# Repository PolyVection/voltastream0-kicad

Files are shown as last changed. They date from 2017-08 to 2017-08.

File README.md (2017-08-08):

# VoltaStream ZERO hardware 

VoltaStream ZERO

PolyVection VoltaStream ZERO is an open source audio streaming solution that runs Linux and features a high quality digital-to-analog converter as well as digital TOSLINK output capability. There is also a 40 way pinheader with access to 28 GPIO's. It is as small as 65 mm x 30 mm and very efficient. This PCB was created using KiCAD 4.0.5.
The whole project is released under the Creative Commons BY-NC-ND 3.0 license. 
For details please refere to the full license text at https://creativecommons.org/licenses/by-nc-nd/3.0/legalcode

If you have any questions don't hesitate to contact us. We are also offering customisation and prototyping services. http://www.voltastream.com

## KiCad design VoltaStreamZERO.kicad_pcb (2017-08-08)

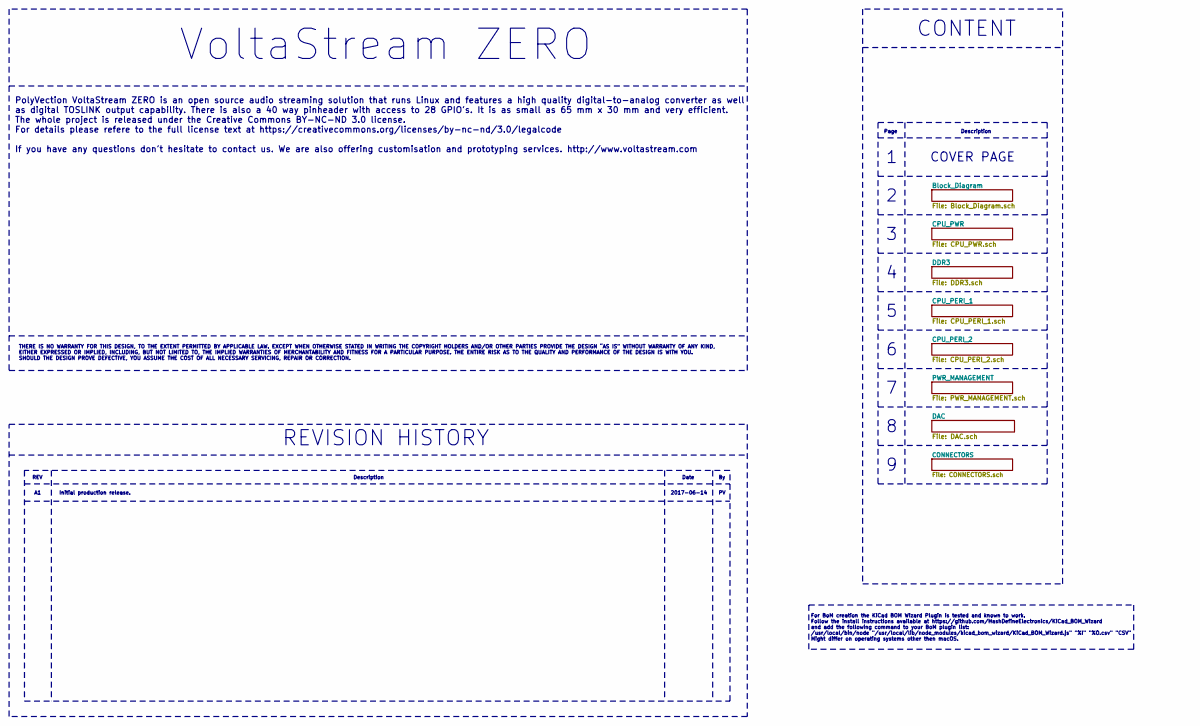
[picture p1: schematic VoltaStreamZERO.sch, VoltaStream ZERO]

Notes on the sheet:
VoltaStream ZERO
REVISION HISTORY
CONTENT
THERE IS NO WARRANTY FOR THIS DESIGN, TO THE EXTENT PERMITTED BY APPLICABLE LAW. EXCEPT WHEN OTHERWISE STATED IN WRITING THE COPYRIGHT HOLDERS AND/OR OTHER PARTIES PROVIDE THE DESIGN “AS IS” WITHOUT WARRANTY OF ANY KIND, EITHER EXPRESSED OR IMPLIED, INCLUDING, BUT NOT LIMITED TO, THE IMPLIED WARRAN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
PolyVection VoltaStream ZERO is an open source audio streaming solution that runs Linux and features a high quality digital-to-analog converter as well as digital TOSLINK output capability. There is also a 40 way pinheader with access to 28 GPIO's. It is as small as 65 mm x 30 mm and very efficient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
Page
Description
COVER PAGE
For BoM creation the KiCad BOM Wizard Plugin is tested and known to work. Follow the install instructions available at https://github.com/HashDefineElectronics/KiCad_BOM_Wizard and add the following command to your BoM plugin list: /usr/local/bin/node "/usr/local/lib/node_modules/kicad_bom_wizard/K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
REV
Date
Initial production release.
2017-06-14

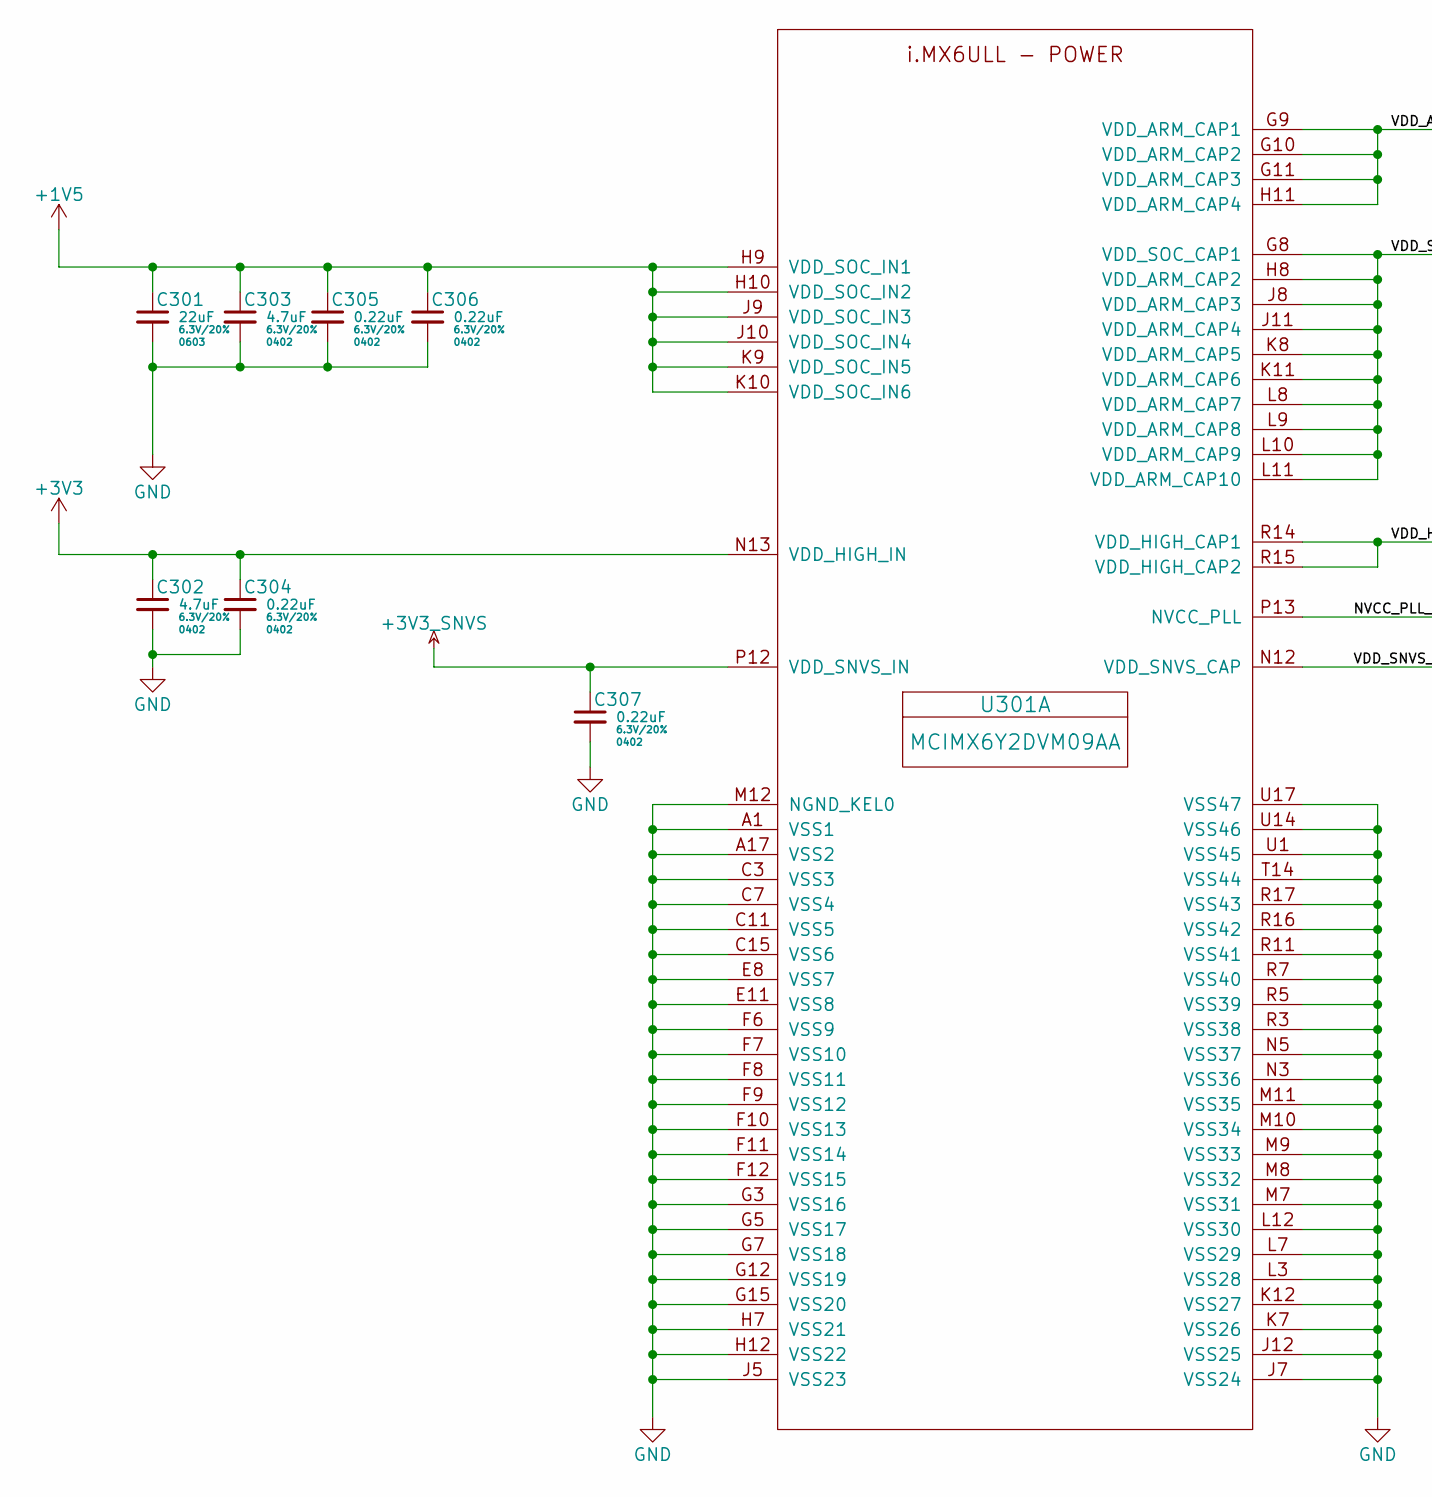
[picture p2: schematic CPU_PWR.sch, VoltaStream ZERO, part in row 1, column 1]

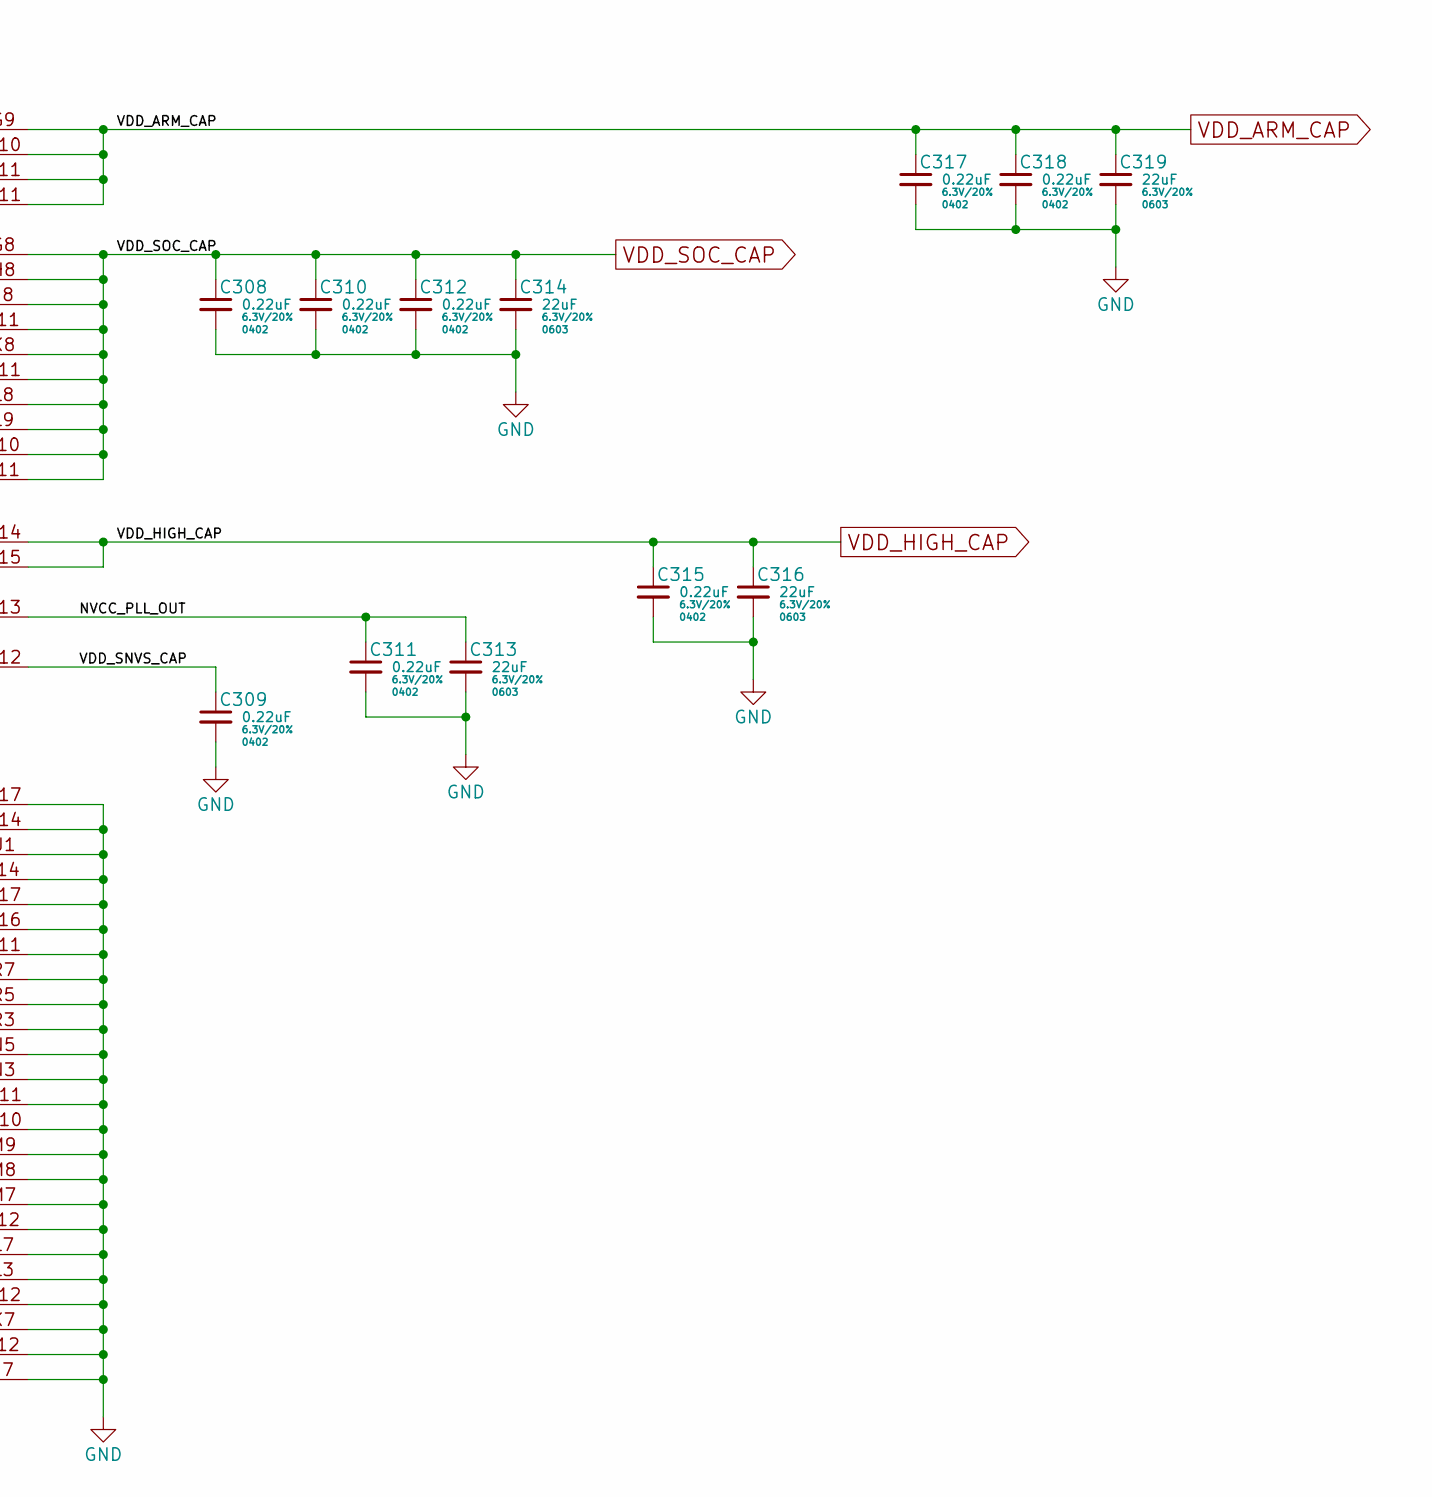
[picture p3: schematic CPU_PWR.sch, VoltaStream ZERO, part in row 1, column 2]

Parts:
C301, C313, C314, C316, C319: 22uF; 0603; Rating 6.3V/20%; Rating2 X5R; Part GRM188R60J226ME0D
C302, C303: 4.7uF; 0402; Rating 6.3V/20%; Rating2 X5R; Part GRM155R60J475ME7D
C304, C305, C306, C307, C308, C309, C310, C311, C312, C315, C317, C318: 0.22uF; 0402; Rating 6.3V/20%; Rating2 X5R; Part GRM155R60J224KE01D
U301: MCIMX6Y2DVM09AA; BGA_14x14; Rating 1x 900 MHz, 32 bit; Part MCIMX6Y2DVM09AA

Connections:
+1V5: C301.1, C303.1, C305.1, C306.1, U301.H9 (VDD_SOC_IN1), U301.H10 (VDD_SOC_IN2), U301.J9 (VDD_SOC_IN3), U301.J10 (VDD_SOC_IN4), U301.K9 (VDD_SOC_IN5), U301.K10 (VDD_SOC_IN6); also elsewhere on the board
+3V3: C302.1, C304.1, U301.N13 (VDD_HIGH_IN); also elsewhere on the board
+3V3_SNVS: C307.1, U301.P12 (VDD_SNVS_IN); also elsewhere on the board
/CPU_PWR/NVCC_PLL_OUT: C311.1, C313.1, U301.P13 (NVCC_PLL)
/CPU_PWR/VDD_SNVS_CAP: C309.1, U301.N12 (VDD_SNVS_CAP)
GND: C301.2, C302.2, C303.2, C304.2, C305.2, C306.2, C307.2, C308.2, C309.2, C310.2, C311.2, C312.2, C313.2, C314.2, C315.2, C316.2, C317.2, C318.2, C319.2, U301.A1 (VSS1), U301.A17 (VSS2), U301.C3 (VSS3), U301.C7 (VSS4), U301.C11 (VSS5), U301.C15 (VSS6), U301.E8 (VSS7), U301.E11 (VSS8), U301.F6 (VSS9), U301.F7 (VSS10), U301.F8 (VSS11), U301.F9 (VSS12), U301.F10 (VSS13), U301.F11 (VSS14), U301.F12 (VSS15), U301.G3 (VSS16), U301.G5 (VSS17), U301.G7 (VSS18), U301.G12 (VSS19), U301.G15 (VSS20), U301.H7 (VSS21), U301.H12 (VSS22), U301.J5 (VSS23), U301.J7 (VSS24), U301.J12 (VSS25), U301.K7 (VSS26), U301.K12 (VSS27), U301.L3 (VSS28), U301.L7 (VSS29), U301.L12 (VSS30), U301.M7 (VSS31), U301.M8 (VSS32), U301.M9 (VSS33), U301.M10 (VSS34), U301.M11 (VSS35), U301.M12 (NGND_KEL0), U301.N3 (VSS36), U301.N5 (VSS37), U301.R3 (VSS38), U301.R5 (VSS39), U301.R7 (VSS40), U301.R11 (VSS41), U301.R16 (VSS42), U301.R17 (VSS43), U301.T14 (VSS44), U301.U1 (VSS45), U301.U14 (VSS46), U301.U17 (VSS47); also elsewhere on the board
VDD_ARM_CAP: C317.1, C318.1, C319.1, U301.G9 (VDD_ARM_CAP1), U301.G10 (VDD_ARM_CAP2), U301.G11 (VDD_ARM_CAP3), U301.H11 (VDD_ARM_CAP4)
VDD_HIGH_CAP: C315.1, C316.1, U301.R14 (VDD_HIGH_CAP1), U301.R15 (VDD_HIGH_CAP2); also elsewhere on the board
VDD_SOC_CAP: C308.1, C310.1, C312.1, C314.1, U301.G8 (VDD_SOC_CAP1), U301.H8 (VDD_ARM_CAP2), U301.J8 (VDD_ARM_CAP3), U301.J11 (VDD_ARM_CAP4), U301.K8 (VDD_ARM_CAP5), U301.K11 (VDD_ARM_CAP6), U301.L8 (VDD_ARM_CAP7), U301.L9 (VDD_ARM_CAP8), U301.L10 (VDD_ARM_CAP9), U301.L11 (VDD_ARM_CAP10)

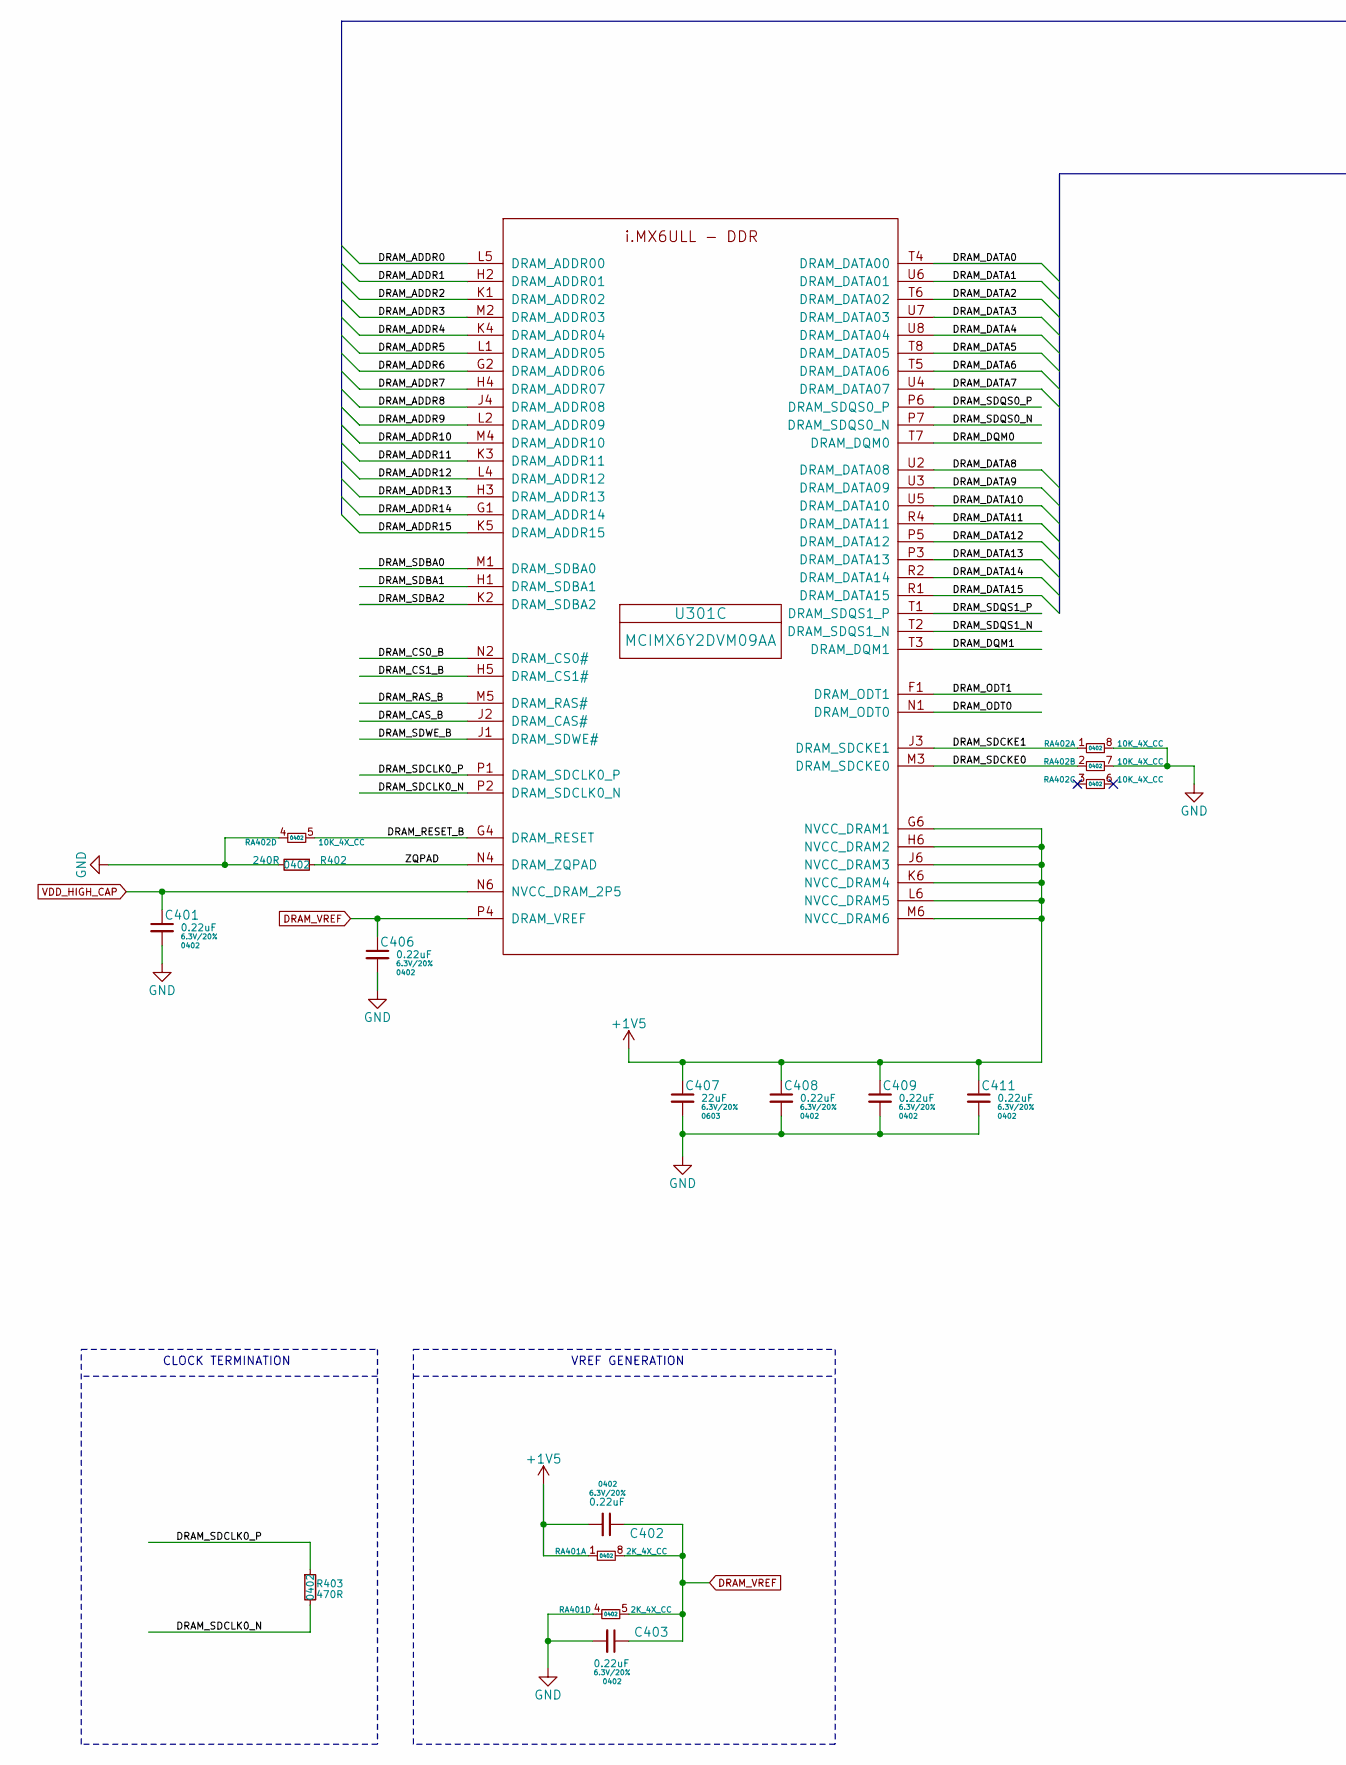
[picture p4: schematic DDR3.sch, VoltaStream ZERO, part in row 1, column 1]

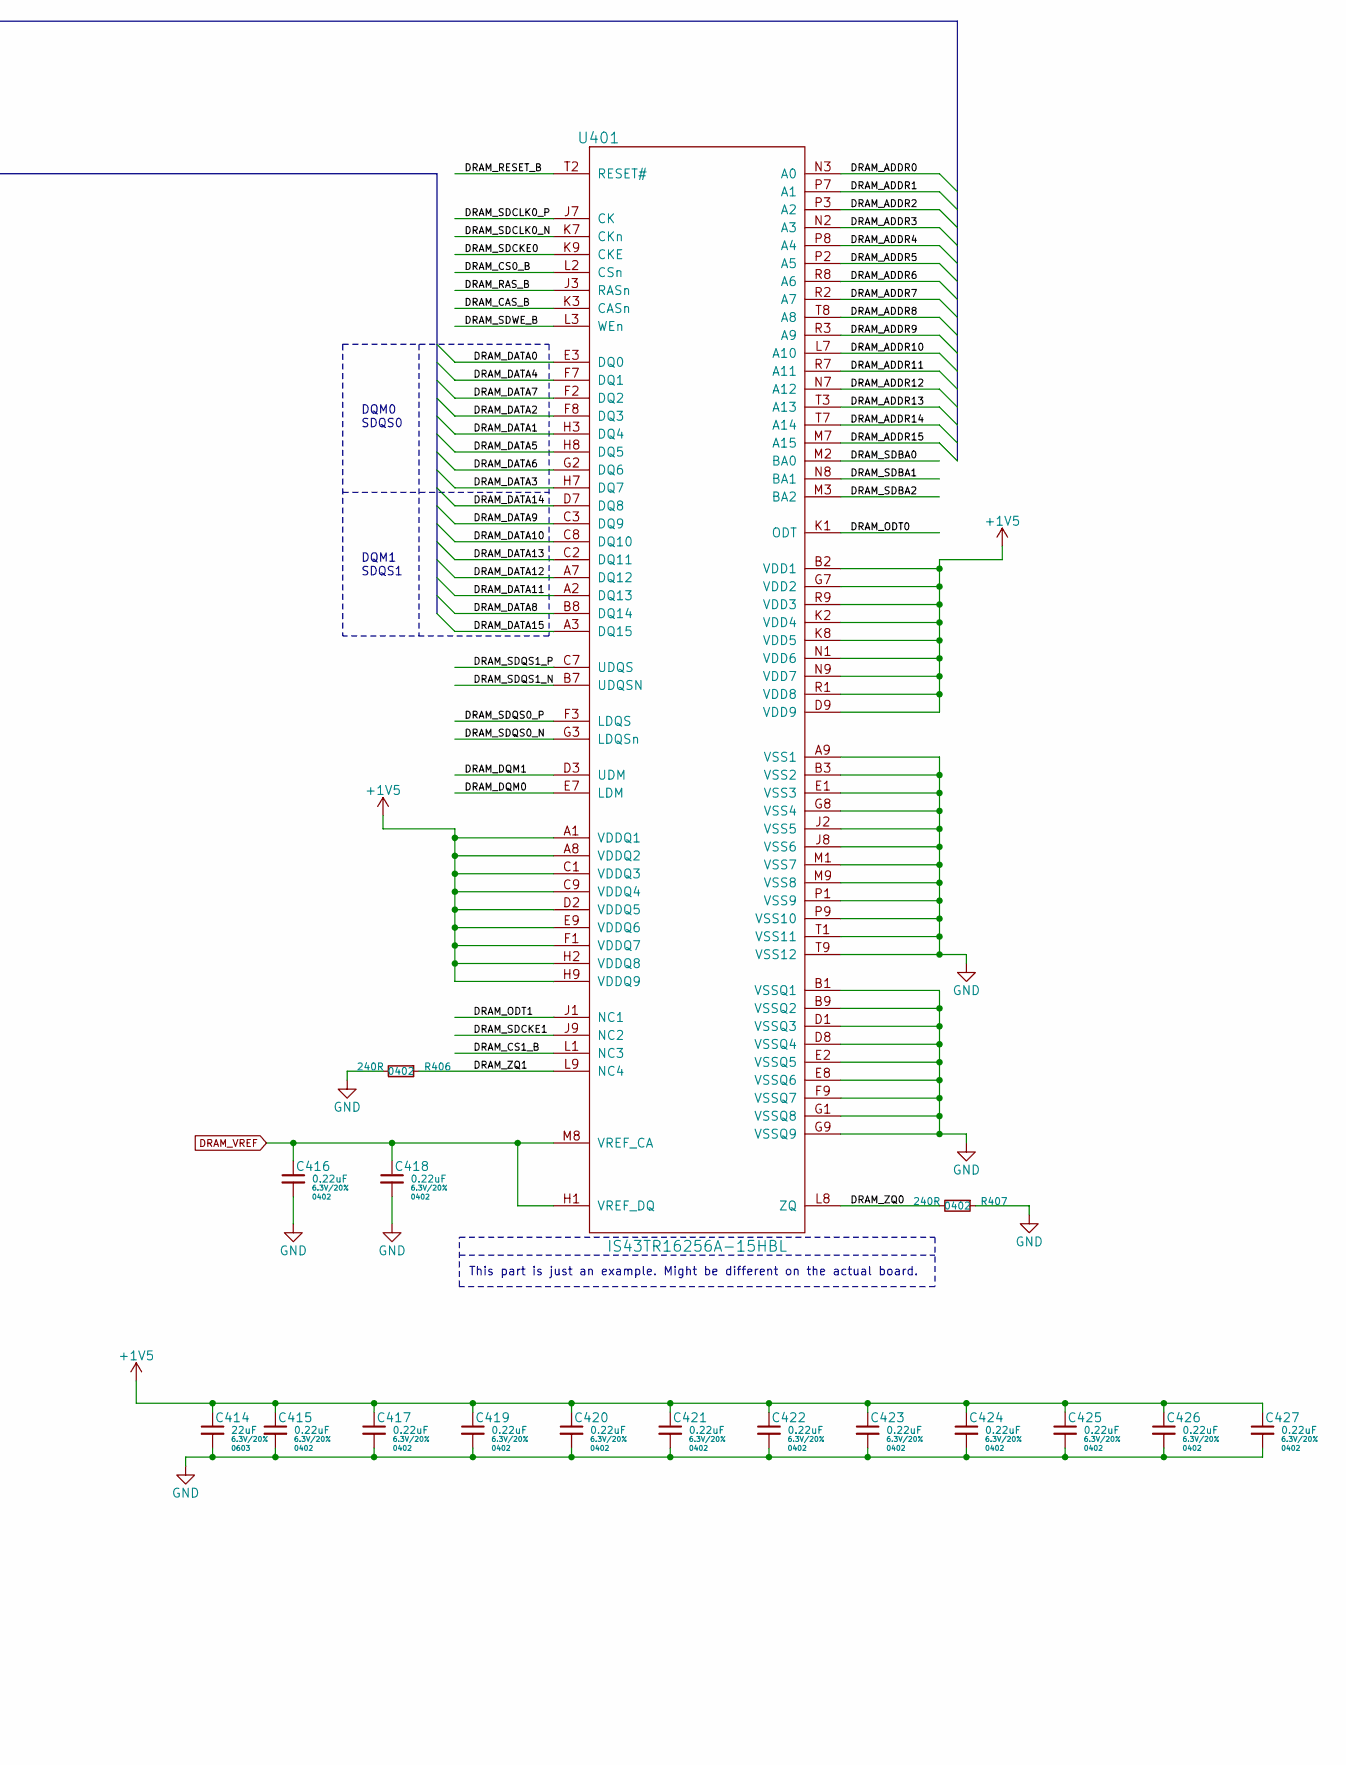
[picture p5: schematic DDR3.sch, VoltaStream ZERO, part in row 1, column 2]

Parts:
C401, C402, C403, C406, C408, C409, C411, C415, C416, C417, C418, C419, C420, C421, C422, C423, C424, C425, C426, C427: 0.22uF; 0402; Rating 6.3V/20%; Rating2 X5R; Part GRM155R60J224KE01D
C407, C414: 22uF; 0603; Rating 6.3V/20%; Rating2 X5R; Part GRM188R60J226ME0D
R402, R406, R407: 240R; 0402; Rating 1% / Thick Film; Part RC0402FR-07240RL
R403: 470R; 0402; Rating 1% / Thick Film; Part RC0402FR-07470RL
RA401: 2K_4X_CC; R_Array_OPT_4x0402; Rating 2K, 5%; Rating2 Concave Array 4x; Part EXB-N8V202JX
RA402: 10K_4X_CC; R_Array_OPT_4x0402; Rating 10K, 5%; Rating2 Concave Array 4x; Part EXB-N8V103JX
U301: MCIMX6Y2DVM09AA; BGA_14x14; Rating 1x 900 MHz, 32 bit; Part MCIMX6Y2DVM09AA
U401: IS43TR16256A-15HBL; FBGA_96_DDR3L; Rating 4G - DDR3; Rating2 512 MB - 1V5; Part IS43TR16256A-15HBL

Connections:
+1V5: C402.2, C407.1, C408.1, C409.1, C411.1, C414.1, C415.1, C417.1, C419.1, C420.1, C421.1, C422.1, C423.1, C424.1, C425.1, C426.1, C427.1, RA401.1, U301.G6 (NVCC_DRAM1), U301.H6 (NVCC_DRAM2), U301.J6 (NVCC_DRAM3), U301.K6 (NVCC_DRAM4), U301.L6 (NVCC_DRAM5), U301.M6 (NVCC_DRAM6), U401.A1 (VDDQ1), U401.A8 (VDDQ2), U401.B2 (VDD1), U401.C1 (VDDQ3), U401.C9 (VDDQ4), U401.D2 (VDDQ5), U401.D9 (VDD9), U401.E9 (VDDQ6), U401.F1 (VDDQ7), U401.G7 (VDD2), U401.H2 (VDDQ8), U401.H9 (VDDQ9), U401.K2 (VDD4), U401.K8 (VDD5), U401.N1 (VDD6), U401.N9 (VDD7), U401.R1 (VDD8), U401.R9 (VDD3); also elsewhere on the board
/DDR3/DRAM_ADDR0: U301.L5 (DRAM_ADDR00), U401.N3 (A0)
/DDR3/DRAM_ADDR1: U301.H2 (DRAM_ADDR01), U401.P7 (A1)
/DDR3/DRAM_ADDR2: U301.K1 (DRAM_ADDR02), U401.P3 (A2)
/DDR3/DRAM_ADDR3: U301.M2 (DRAM_ADDR03), U401.N2 (A3)
/DDR3/DRAM_ADDR4: U301.K4 (DRAM_ADDR04), U401.P8 (A4)
/DDR3/DRAM_ADDR5: U301.L1 (DRAM_ADDR05), U401.P2 (A5)
/DDR3/DRAM_ADDR6: U301.G2 (DRAM_ADDR06), U401.R8 (A6)
/DDR3/DRAM_ADDR7: U301.H4 (DRAM_ADDR07), U401.R2 (A7)
/DDR3/DRAM_ADDR8: U301.J4 (DRAM_ADDR08), U401.T8 (A8)
/DDR3/DRAM_ADDR9: U301.L2 (DRAM_ADDR09), U401.R3 (A9)
/DDR3/DRAM_ADDR10: U301.M4 (DRAM_ADDR10), U401.L7 (A10)
/DDR3/DRAM_ADDR11: U301.K3 (DRAM_ADDR11), U401.R7 (A11)
/DDR3/DRAM_ADDR12: U301.L4 (DRAM_ADDR12), U401.N7 (A12)
/DDR3/DRAM_ADDR13: U301.H3 (DRAM_ADDR13), U401.T3 (A13)
/DDR3/DRAM_ADDR14: U301.G1 (DRAM_ADDR14), U401.T7 (A14)
/DDR3/DRAM_ADDR15: U301.K5 (DRAM_ADDR15), U401.M7 (A15)
/DDR3/DRAM_CAS_B: U301.J2 (DRAM_CAS#), U401.K3 (CASn)
/DDR3/DRAM_CS0_B: U301.N2 (DRAM_CS0#), U401.L2 (CSn)
/DDR3/DRAM_CS1_B: U301.H5 (DRAM_CS1#), U401.L1 (NC3)
/DDR3/DRAM_DATA0: U301.T4 (DRAM_DATA00), U401.E3 (DQ0)
/DDR3/DRAM_DATA1: U301.U6 (DRAM_DATA01), U401.H3 (DQ4)
/DDR3/DRAM_DATA2: U301.T6 (DRAM_DATA02), U401.F8 (DQ3)
/DDR3/DRAM_DATA3: U301.U7 (DRAM_DATA03), U401.H7 (DQ7)
/DDR3/DRAM_DATA4: U301.U8 (DRAM_DATA04), U401.F7 (DQ1)
/DDR3/DRAM_DATA5: U301.T8 (DRAM_DATA05), U401.H8 (DQ5)
/DDR3/DRAM_DATA6: U301.T5 (DRAM_DATA06), U401.G2 (DQ6)
/DDR3/DRAM_DATA7: U301.U4 (DRAM_DATA07), U401.F2 (DQ2)
/DDR3/DRAM_DATA8: U301.U2 (DRAM_DATA08), U401.B8 (DQ14)
/DDR3/DRAM_DATA9: U301.U3 (DRAM_DATA09), U401.C3 (DQ9)
/DDR3/DRAM_DATA10: U301.U5 (DRAM_DATA10), U401.C8 (DQ10)
/DDR3/DRAM_DATA11: U301.R4 (DRAM_DATA11), U401.A2 (DQ13)
/DDR3/DRAM_DATA12: U301.P5 (DRAM_DATA12), U401.A7 (DQ12)
/DDR3/DRAM_DATA13: U301.P3 (DRAM_DATA13), U401.C2 (DQ11)
/DDR3/DRAM_DATA14: U301.R2 (DRAM_DATA14), U401.D7 (DQ8)
/DDR3/DRAM_DATA15: U301.R1 (DRAM_DATA15), U401.A3 (DQ15)
/DDR3/DRAM_DQM0: U301.T7 (DRAM_DQM0), U401.E7 (LDM)
/DDR3/DRAM_DQM1: U301.T3 (DRAM_DQM1), U401.D3 (UDM)
/DDR3/DRAM_ODT0: U301.N1 (DRAM_ODT0), U401.K1 (ODT)
/DDR3/DRAM_ODT1: U301.F1 (DRAM_ODT1), U401.J1 (NC1)
/DDR3/DRAM_RAS_B: U301.M5 (DRAM_RAS#), U401.J3 (RASn)
/DDR3/DRAM_RESET_B: RA402.5 (R1), U301.G4 (DRAM_RESET), U401.T2 (RESET#)
/DDR3/DRAM_SDBA0: U301.M1 (DRAM_SDBA0), U401.M2 (BA0)
/DDR3/DRAM_SDBA1: U301.H1 (DRAM_SDBA1), U401.N8 (BA1)
/DDR3/DRAM_SDBA2: U301.K2 (DRAM_SDBA2), U401.M3 (BA2)
/DDR3/DRAM_SDCKE0: RA402.2 (P1), U301.M3 (DRAM_SDCKE0), U401.K9 (CKE)
/DDR3/DRAM_SDCKE1: RA402.1, U301.J3 (DRAM_SDCKE1), U401.J9 (NC2)
/DDR3/DRAM_SDCLK0_N: R403.2, U301.P2 (DRAM_SDCLK0_N), U401.K7 (CKn)
/DDR3/DRAM_SDCLK0_P: R403.1, U301.P1 (DRAM_SDCLK0_P), U401.J7 (CK)
/DDR3/DRAM_SDQS0_N: U301.P7 (DRAM_SDQS0_N), U401.G3 (LDQSn)
/DDR3/DRAM_SDQS0_P: U301.P6 (DRAM_SDQS0_P), U401.F3 (LDQS)
/DDR3/DRAM_SDQS1_N: U301.T2 (DRAM_SDQS1_N), U401.B7 (UDQSN)
/DDR3/DRAM_SDQS1_P: U301.T1 (DRAM_SDQS1_P), U401.C7 (UDQS)
/DDR3/DRAM_SDWE_B: U301.J1 (DRAM_SDWE#), U401.L3 (WEn)
/DDR3/DRAM_ZQ0: R407.2, U401.L8 (ZQ)
/DDR3/DRAM_ZQ1: R406.1, U401.L9 (NC4)
/DDR3/ZQPAD: R402.1, U301.N4 (DRAM_ZQPAD)
DRAM_VREF: C402.1, C403.1, C406.1, C416.1, C418.1, RA401.5 (R1), RA401.8 (R1), U301.P4 (DRAM_VREF), U401.H1 (VREF_DQ), U401.M8 (VREF_CA)
GND: C401.2, C403.2, C406.2, C407.2, C408.2, C409.2, C411.2, C414.2, C415.2, C416.2, C417.2, C418.2, C419.2, C420.2, C421.2, C422.2, C423.2, C424.2, C425.2, C426.2, C427.2, R402.2, R406.2, R407.1, RA401.4 (P1), RA402.4 (P1), RA402.7 (R1), RA402.8 (R1), U401.A9 (VSS1), U401.B1 (VSSQ1), U401.B3 (VSS2), U401.B9 (VSSQ2), U401.D1 (VSSQ3), U401.D8 (VSSQ4), U401.E1 (VSS3), U401.E2 (VSSQ5), U401.E8 (VSSQ6), U401.F9 (VSSQ7), U401.G1 (VSSQ8), U401.G8 (VSS4), U401.G9 (VSSQ9), U401.J2 (VSS5), U401.J8 (VSS6), U401.M1 (VSS7), U401.M9 (VSS8), U401.P1 (VSS9), U401.P9 (VSS10), U401.T1 (VSS11), U401.T9 (VSS12); also elsewhere on the board
VDD_HIGH_CAP: C401.1, U301.N6 (NVCC_DRAM_2P5); also elsewhere on the board

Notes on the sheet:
CLOCK TERMINATION
VREF GENERATION
This part is just an example. Might be different on the actual board.
DQM0 SDQS0
DQM1 SDQS1

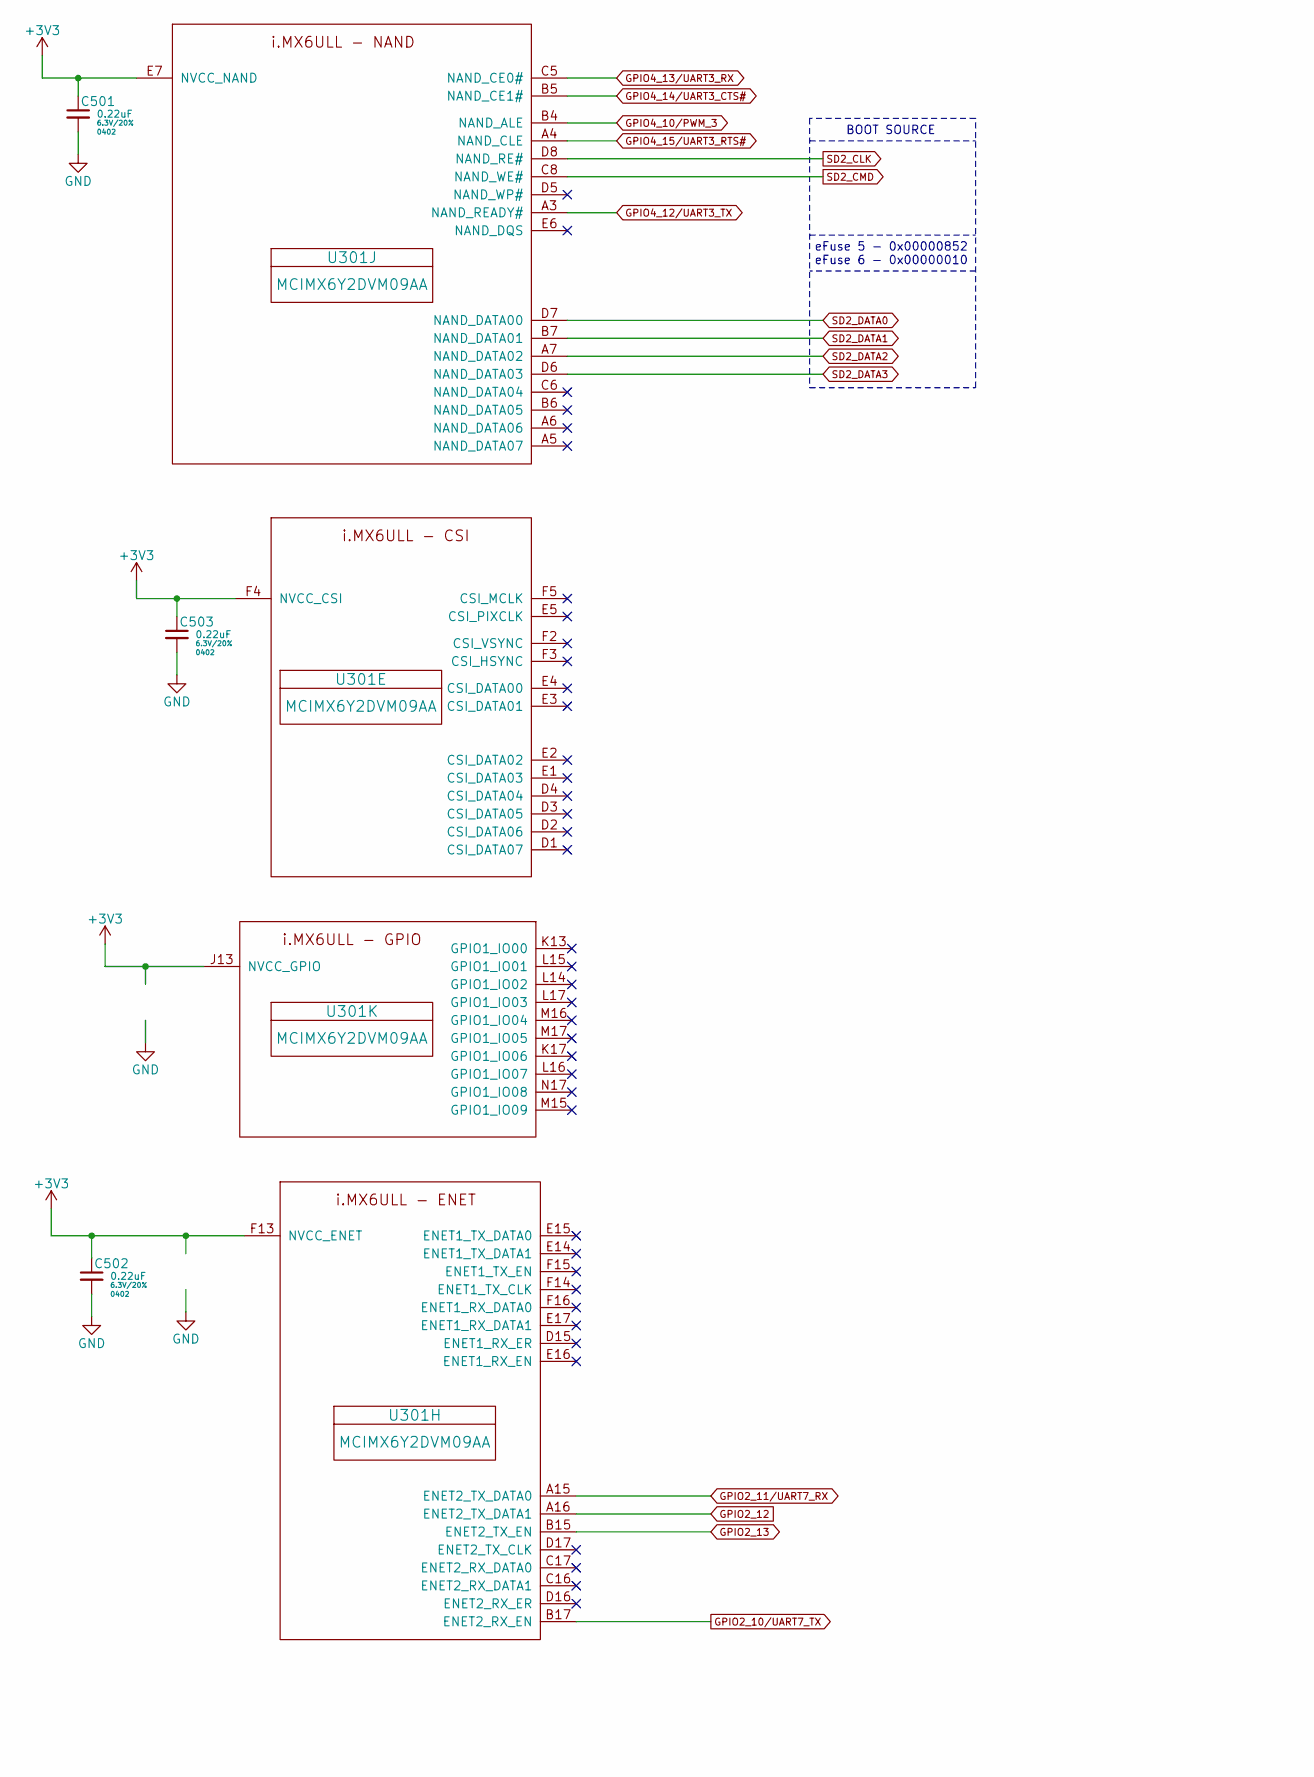
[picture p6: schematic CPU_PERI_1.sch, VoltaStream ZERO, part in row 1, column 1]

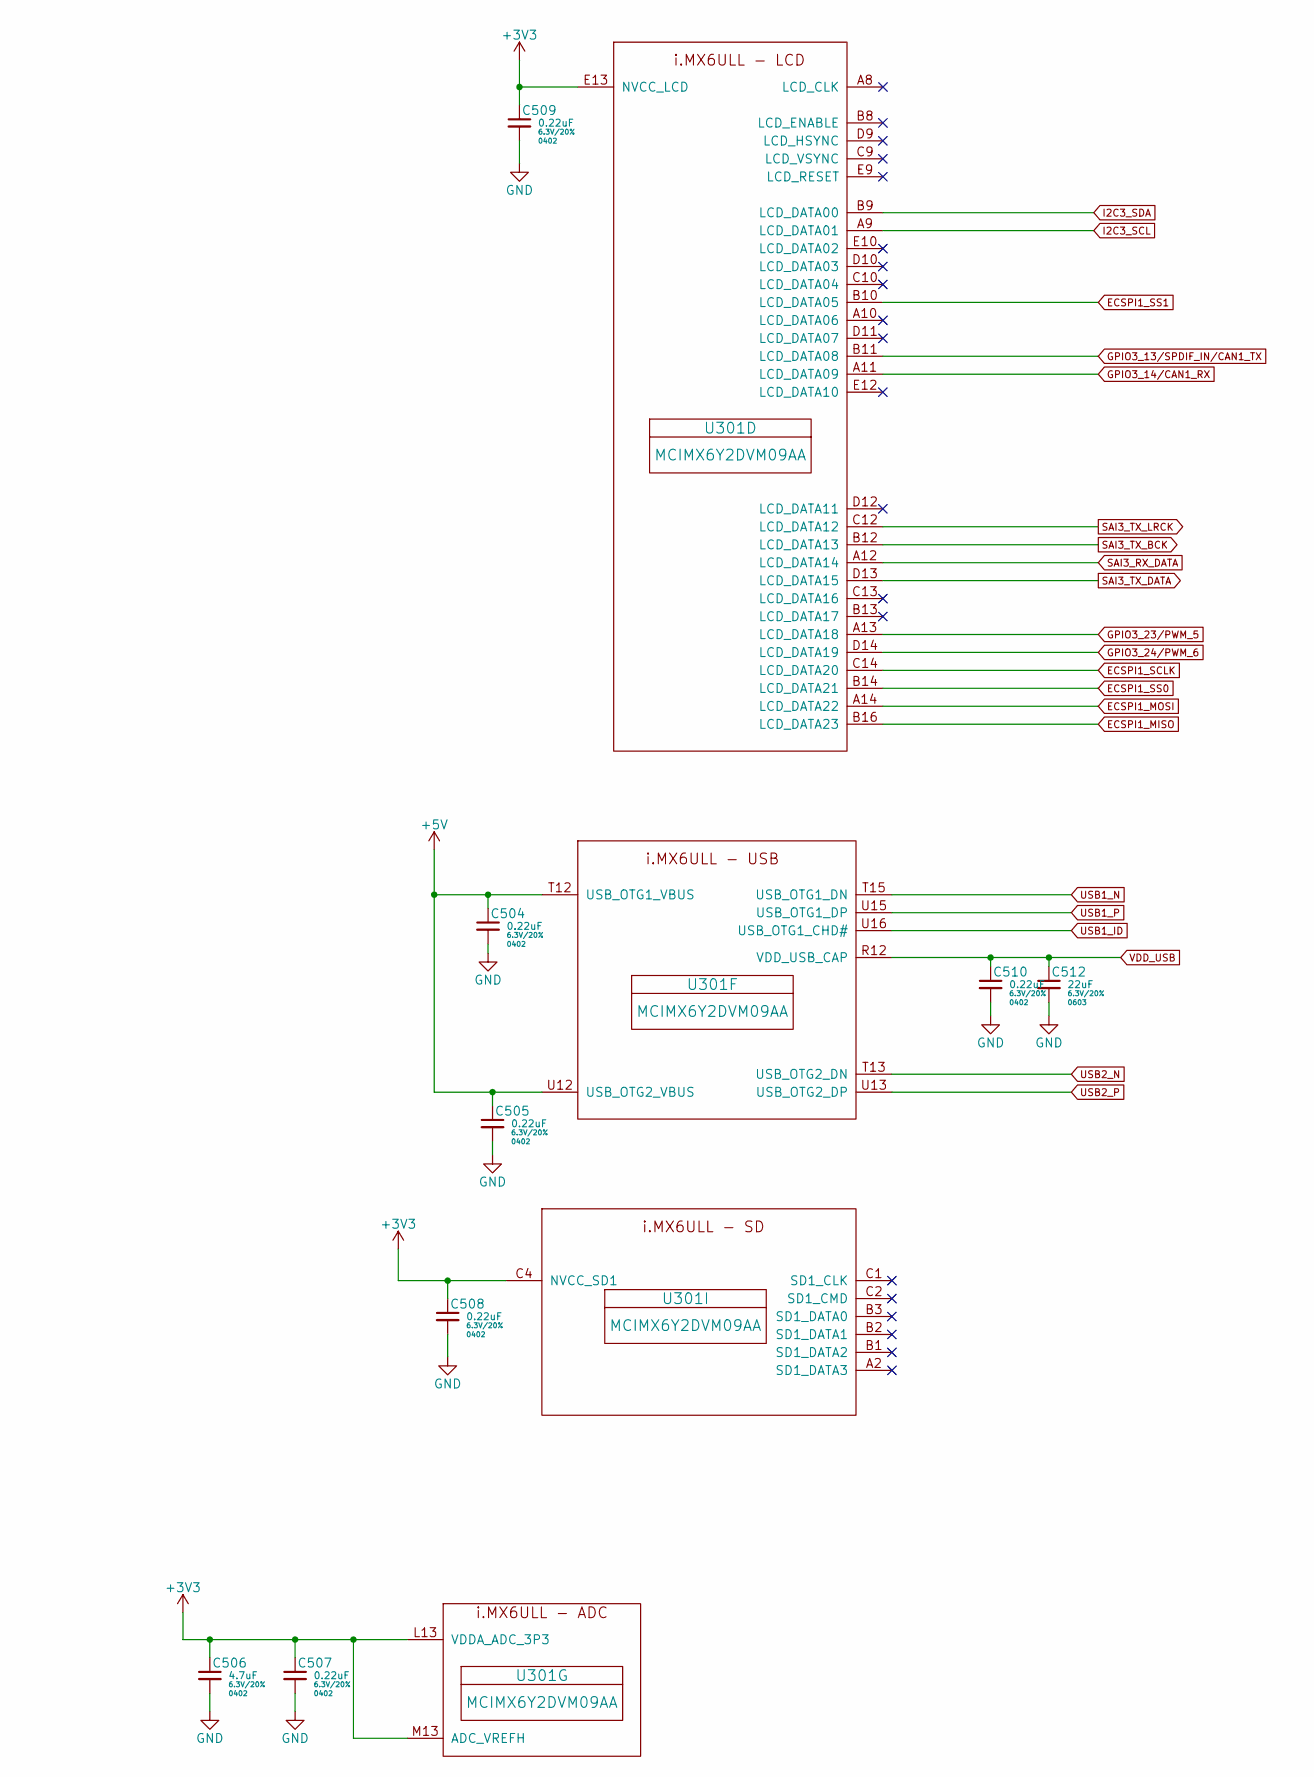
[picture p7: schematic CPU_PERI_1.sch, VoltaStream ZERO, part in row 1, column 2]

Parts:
C501, C502, C503, C504, C505, C507, C508, C509, C510: 0.22uF; 0402; Rating 6.3V/20%; Rating2 X5R; Part GRM155R60J224KE01D
C506: 4.7uF; 0402; Rating 6.3V/20%; Rating2 X5R; Part GRM155R60J475ME7D
C512: 22uF; 0603; Rating 6.3V/20%; Rating2 X5R; Part GRM188R60J226ME0D
U301: MCIMX6Y2DVM09AA; BGA_14x14; Rating 1x 900 MHz, 32 bit; Part MCIMX6Y2DVM09AA

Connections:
+3V3: C501.1, C502.1, C503.1, C506.1, C507.1, C508.1, C509.1, U301.C4 (NVCC_SD1), U301.E7 (NVCC_NAND), U301.E13 (NVCC_LCD), U301.F4 (NVCC_CSI), U301.F13 (NVCC_ENET), U301.J13 (NVCC_GPIO), U301.L13 (VDDA_ADC_3P3), U301.M13 (ADC_VREFH); also elsewhere on the board
+5V: C504.1, C505.1, U301.T12 (USB_OTG1_VBUS), U301.U12 (USB_OTG2_VBUS); also elsewhere on the board
ECSPI1_MISO: U301.B16 (LCD_DATA23); also elsewhere on the board
ECSPI1_MOSI: U301.A14 (LCD_DATA22); also elsewhere on the board
ECSPI1_SCLK: U301.C14 (LCD_DATA20); also elsewhere on the board
ECSPI1_SS0: U301.B14 (LCD_DATA21); also elsewhere on the board
ECSPI1_SS1: U301.B10 (LCD_DATA05); also elsewhere on the board
GND: C501.2, C502.2, C503.2, C504.2, C505.2, C506.2, C507.2, C508.2, C509.2, C510.2, C512.2; also elsewhere on the board
GPIO2_10/UART7_TX: U301.B17 (ENET2_RX_EN); also elsewhere on the board
GPIO2_11/UART7_RX: U301.A15 (ENET2_TX_DATA0); also elsewhere on the board
GPIO2_12: U301.A16 (ENET2_TX_DATA1); also elsewhere on the board
GPIO2_13: U301.B15 (ENET2_TX_EN); also elsewhere on the board
GPIO3_13/SPDIF_IN/CAN1_TX: U301.B11 (LCD_DATA08); also elsewhere on the board
GPIO3_14/CAN1_RX: U301.A11 (LCD_DATA09); also elsewhere on the board
GPIO3_23/PWM_5: U301.A13 (LCD_DATA18); also elsewhere on the board
GPIO3_24/PWM_6: U301.D14 (LCD_DATA19); also elsewhere on the board
GPIO4_10/PWM_3: U301.B4 (NAND_ALE); also elsewhere on the board
GPIO4_12/UART3_TX: U301.A3 (NAND_READY#); also elsewhere on the board
GPIO4_13/UART3_RX: U301.C5 (NAND_CE0#); also elsewhere on the board
GPIO4_14/UART3_CTS#: U301.B5 (NAND_CE1#); also elsewhere on the board
GPIO4_15/UART3_RTS#: U301.A4 (NAND_CLE); also elsewhere on the board
I2C3_SCL: U301.A9 (LCD_DATA01); also elsewhere on the board
I2C3_SDA: U301.B9 (LCD_DATA00); also elsewhere on the board
SAI3_RX_DATA: U301.A12 (LCD_DATA14); also elsewhere on the board
SAI3_TX_BCK: U301.B12 (LCD_DATA13); also elsewhere on the board
SAI3_TX_DATA: U301.D13 (LCD_DATA15); also elsewhere on the board
SAI3_TX_LRCK: U301.C12 (LCD_DATA12); also elsewhere on the board
SD2_CLK: U301.D8 (NAND_RE#); also elsewhere on the board
SD2_CMD: U301.C8 (NAND_WE#); also elsewhere on the board
SD2_DATA0: U301.D7 (NAND_DATA00); also elsewhere on the board
SD2_DATA1: U301.B7 (NAND_DATA01); also elsewhere on the board
SD2_DATA2: U301.A7 (NAND_DATA02); also elsewhere on the board
SD2_DATA3: U301.D6 (NAND_DATA03); also elsewhere on the board
USB1_ID: U301.U16 (USB_OTG1_CHD#)
USB1_N: U301.T15 (USB_OTG1_DN); also elsewhere on the board
USB1_P: U301.U15 (USB_OTG1_DP); also elsewhere on the board
USB2_N: U301.T13 (USB_OTG2_DN); also elsewhere on the board
USB2_P: U301.U13 (USB_OTG2_DP); also elsewhere on the board
VDD_USB: C510.1, C512.1, U301.R12 (VDD_USB_CAP)

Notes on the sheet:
BOOT SOURCE
eFuse 5 - 0x00000852 eFuse 6 - 0x00000010

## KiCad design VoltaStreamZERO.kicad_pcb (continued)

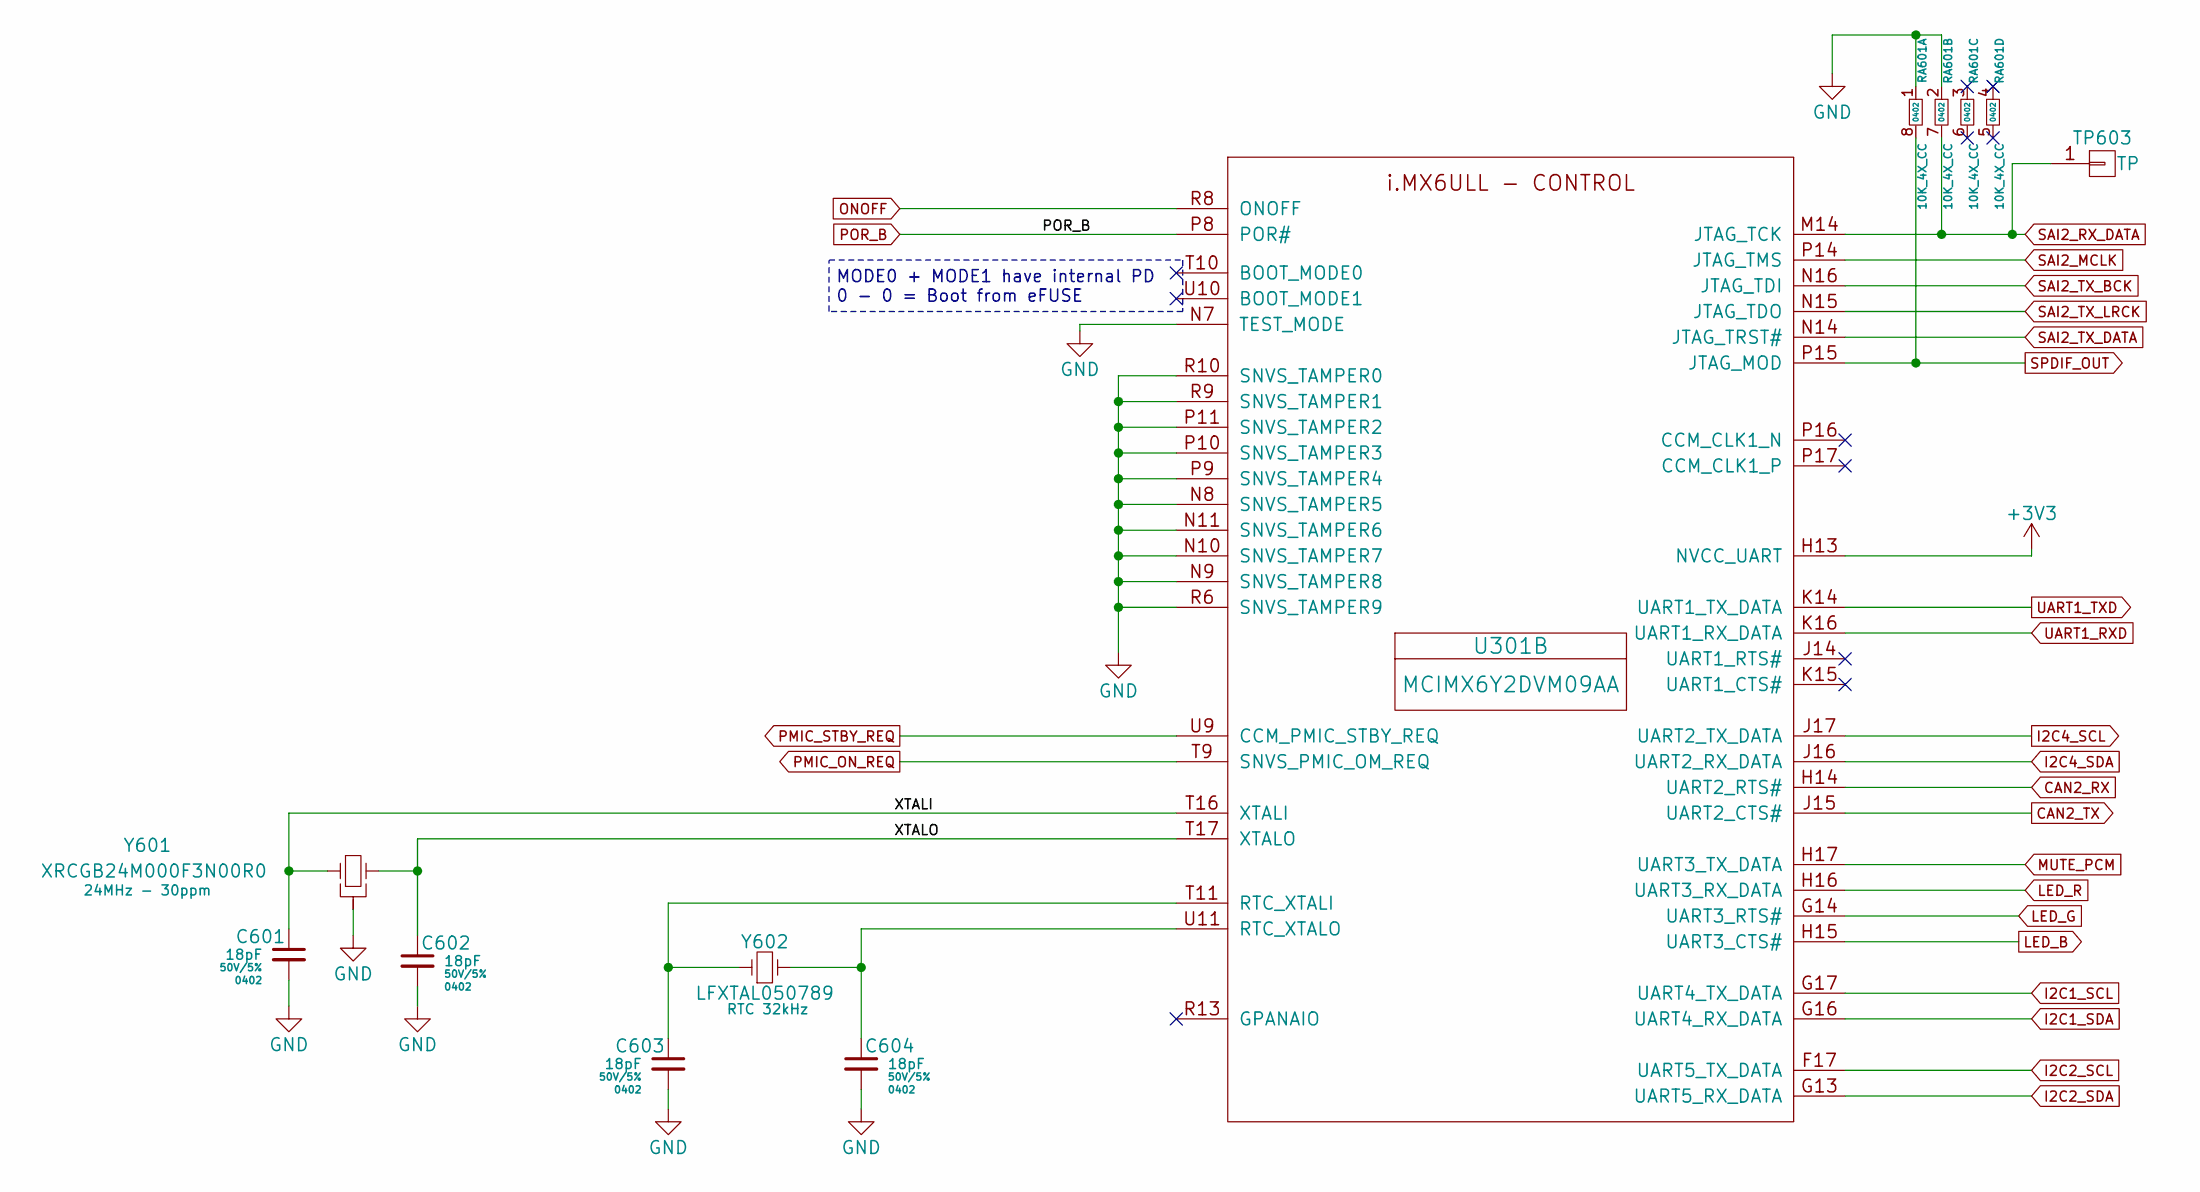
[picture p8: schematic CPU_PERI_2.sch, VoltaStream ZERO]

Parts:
C601, C602, C603, C604: 18pF; 0402; Rating 50V/5%; Rating2 C0G; Part GRM1555C1H180JA01D
RA601: 10K_4X_CC; R_Array_OPT_4x0402; Rating 10K, 5%; Rating2 Concave Array 4x; Part EXB-N8V103JX
TP603: TP; TP_10; Rating NoMask; Part TestPoint
U301: MCIMX6Y2DVM09AA; BGA_14x14; Rating 1x 900 MHz, 32 bit; Part MCIMX6Y2DVM09AA
Y601: XRCGB24M000F3N00R0; OSZ_2x1.6; Rating 24MHz - 30ppm; Rating2 6pF - 2x1.6mm; Part XRCGB24M000F3N00R0
Y602: LFXTAL050789; OSZ_2x1.2; Rating RTC 32kHz; Part LFXTAL050789Reel

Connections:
+3V3: U301.H13 (NVCC_UART); also elsewhere on the board
/CPU_PERI_2/XTALI: C601.1, U301.T16 (XTALI), Y601.1
/CPU_PERI_2/XTALO: C602.1, U301.T17 (XTALO), Y601.2
CAN2_RX: U301.H14 (UART2_RTS#)
CAN2_TX: U301.J15 (UART2_CTS#)
GND: C601.2, C602.2, C603.2, C604.2, RA601.1, RA601.2 (P1), U301.N7 (TEST_MODE), U301.N8 (SNVS_TAMPER5), U301.N9 (SNVS_TAMPER8), U301.N10 (SNVS_TAMPER7), U301.N11 (SNVS_TAMPER6), U301.P9 (SNVS_TAMPER4), U301.P10 (SNVS_TAMPER3), U301.P11 (SNVS_TAMPER2), U301.R6 (SNVS_TAMPER9), U301.R9 (SNVS_TAMPER1), U301.R10 (SNVS_TAMPER0), Y601.G; also elsewhere on the board
I2C1_SCL: U301.G17 (UART4_TX_DATA); also elsewhere on the board
I2C1_SDA: U301.G16 (UART4_RX_DATA); also elsewhere on the board
I2C2_SCL: U301.F17 (UART5_TX_DATA)
I2C2_SDA: U301.G13 (UART5_RX_DATA)
I2C4_SCL: U301.J17 (UART2_TX_DATA); also elsewhere on the board
I2C4_SDA: U301.J16 (UART2_RX_DATA); also elsewhere on the board
LED_B: U301.H15 (UART3_CTS#); also elsewhere on the board
LED_G: U301.G14 (UART3_RTS#); also elsewhere on the board
LED_R: U301.H16 (UART3_RX_DATA); also elsewhere on the board
MUTE_PCM: U301.H17 (UART3_TX_DATA); also elsewhere on the board
unnamed: C603.1, U301.T11 (RTC_XTALI), Y602.1
unnamed: C604.1, U301.U11 (RTC_XTALO), Y602.2
ONOFF: U301.R8 (ONOFF); also elsewhere on the board
PMIC_ON_REQ: U301.T9 (SNVS_PMIC_OM_REQ); also elsewhere on the board
PMIC_STBY_REQ: U301.U9 (CCM_PMIC_STBY_REQ)
POR_B: U301.P8 (POR#); also elsewhere on the board
SAI2_MCLK: U301.P14 (JTAG_TMS); also elsewhere on the board
SAI2_RX_DATA: RA601.7 (R1), TP603.1, U301.M14 (JTAG_TCK)
SAI2_TX_BCK: U301.N16 (JTAG_TDI); also elsewhere on the board
SAI2_TX_DATA: U301.N14 (JTAG_TRST#); also elsewhere on the board
SAI2_TX_LRCK: U301.N15 (JTAG_TDO); also elsewhere on the board
SPDIF_OUT: RA601.8 (R1), U301.P15 (JTAG_MOD); also elsewhere on the board
UART1_RXD: U301.K16 (UART1_RX_DATA); also elsewhere on the board
UART1_TXD: U301.K14 (UART1_TX_DATA); also elsewhere on the board

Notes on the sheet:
MODE0 + MODE1 have internal PD 0 - 0 = Boot from eFUSE

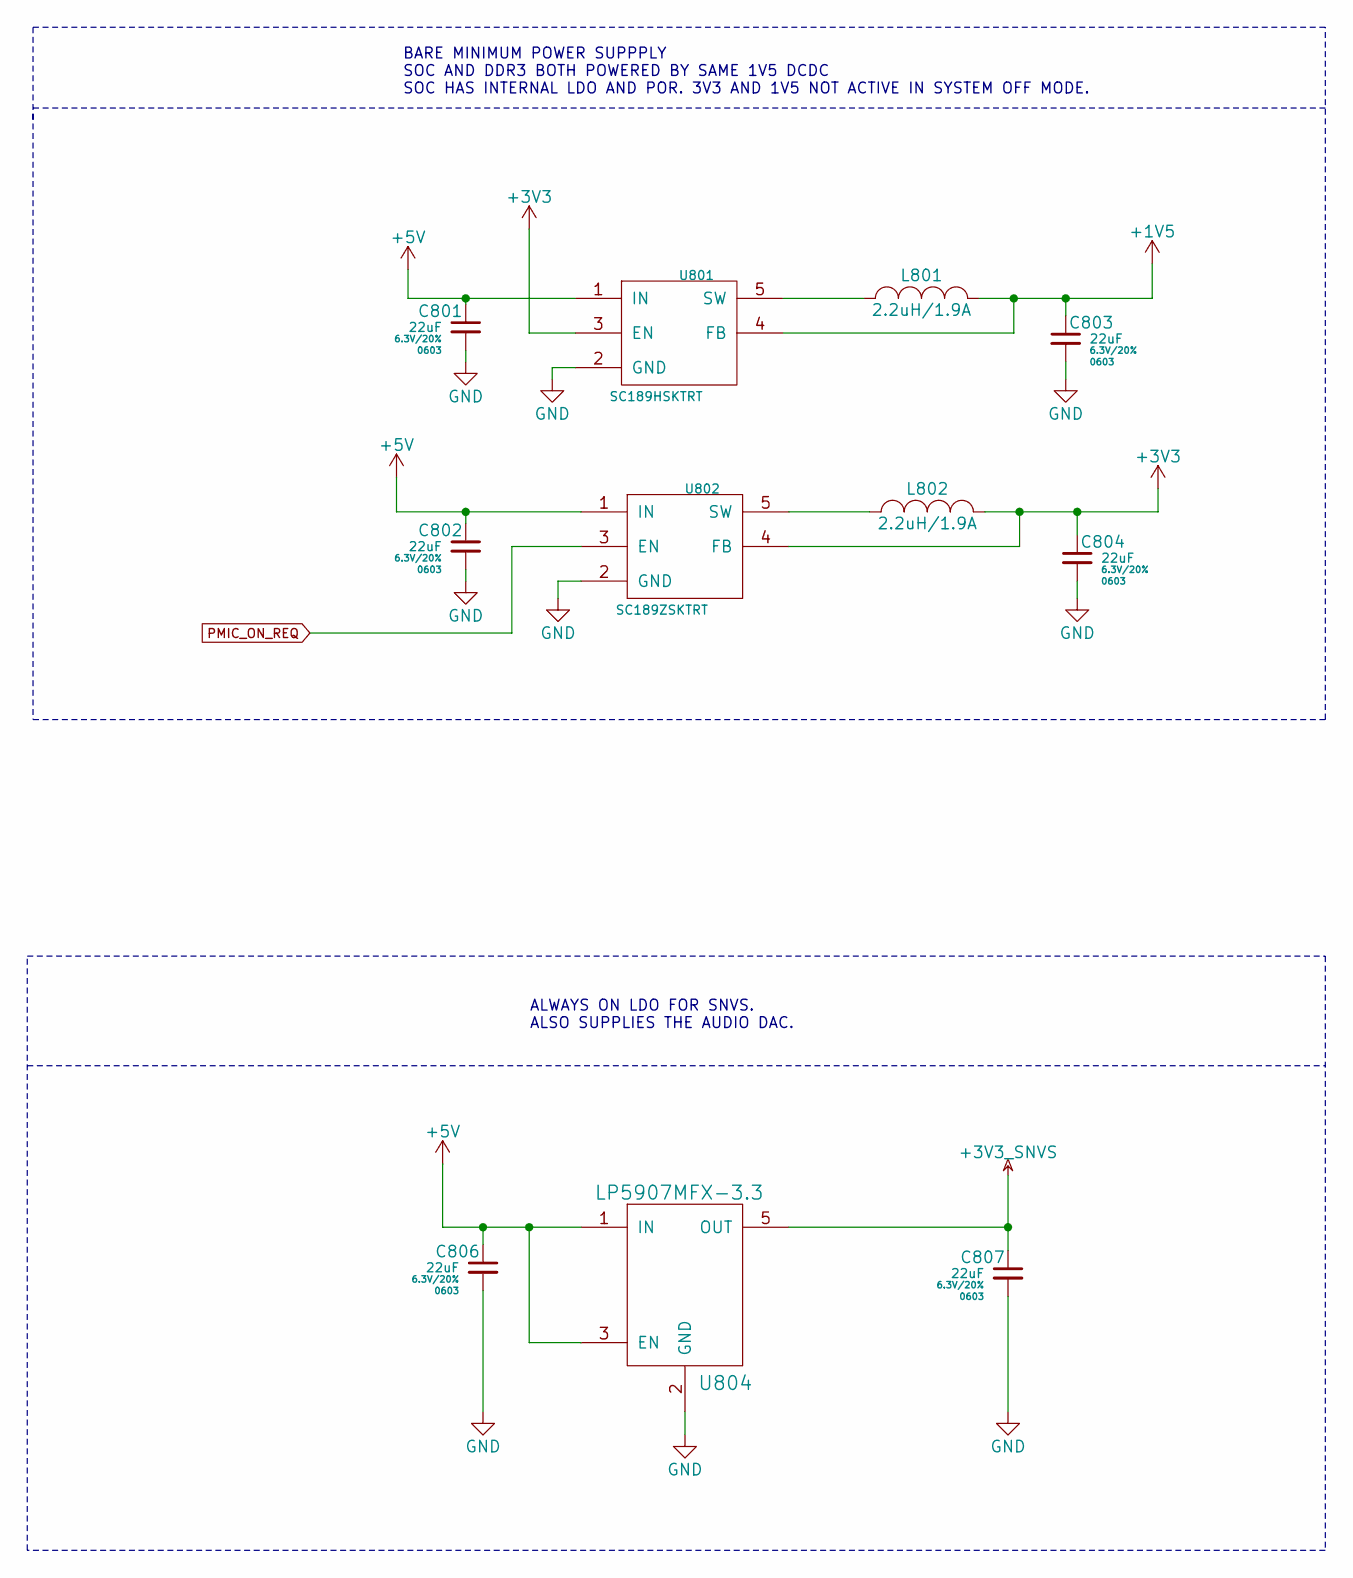
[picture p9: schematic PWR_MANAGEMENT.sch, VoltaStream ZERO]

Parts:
C801, C802, C803, C804, C806, C807: 22uF; 0603; Rating 6.3V/20%; Rating2 X5R; Part GRM188R60J226ME0D
L801, L802: 2.2uH/1.9A; MAMK2520T2R2M; Rating 2.2uH / 1.9A; Part MAMK2520T2R2M
U801: SC189HSKTRT; SOT-23-5; Rating 1V5 1.5A 2.5MHz; Rating2 STEP DOWN; Part SC189HSKTRT
U802: SC189ZSKTRT; SOT-23-5; Rating 3V3 1.5A 2.5MHz; Rating2 STEP DOWN; Part SC189ZSKTRT
U804: LP5907MFX-3.3; SOT-23-5; Rating 3V3 LDO LOW-NOISE; Rating2 250mA; Part LP5907MFX-3.3

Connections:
+1V5: C803.1, L801.2, U801.4 (FB); also elsewhere on the board
+3V3: C804.1, L802.2, U801.3 (EN), U802.4 (FB); also elsewhere on the board
+3V3_SNVS: C807.1, U804.5 (OUT); also elsewhere on the board
+5V: C801.1, C802.1, C806.1, U801.1 (IN), U802.1 (IN), U804.1 (IN), U804.3 (EN); also elsewhere on the board
GND: C801.2, C802.2, C803.2, C804.2, C806.2, C807.2, U801.2 (GND), U802.2 (GND), U804.2 (GND); also elsewhere on the board
unnamed: L801.1, U801.5 (SW)
unnamed: L802.1, U802.5 (SW)
PMIC_ON_REQ: U802.3 (EN); also elsewhere on the board

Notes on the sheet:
BARE MINIMUM POWER SUPPPLY SOC AND DDR3 BOTH POWERED BY SAME 1V5 DCDC SOC HAS INTERNAL LDO AND POR. 3V3 AND 1V5 NOT ACTIVE IN SYSTEM OFF MODE.
ALWAYS ON LDO FOR SNVS. ALSO SUPPLIES THE AUDIO DAC.

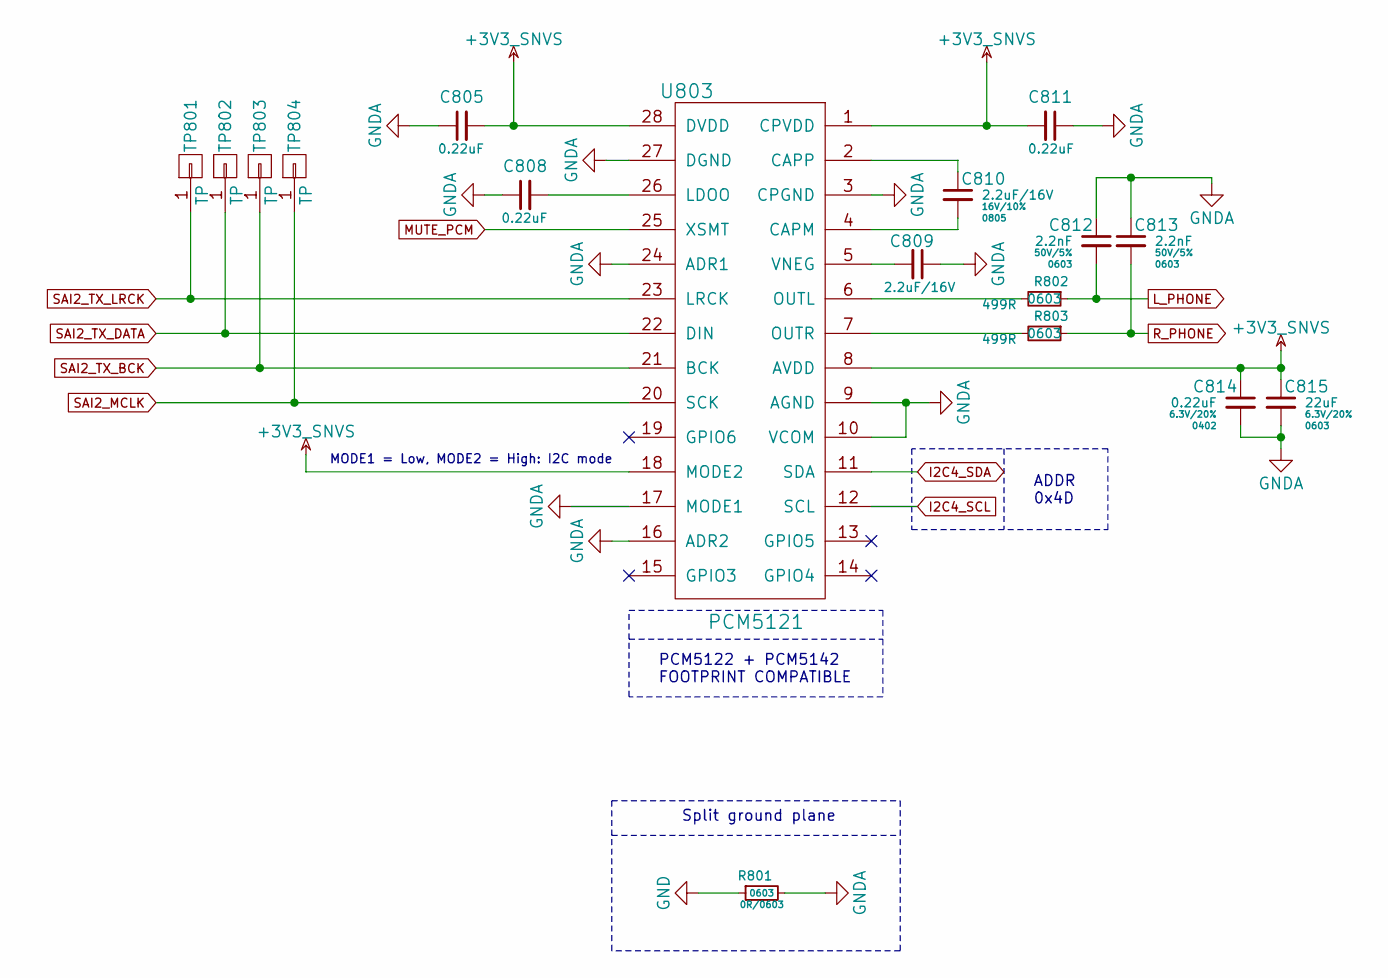
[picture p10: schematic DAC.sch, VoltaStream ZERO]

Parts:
C805, C808, C811, C814: 0.22uF; 0402; Rating 6.3V/20%; Rating2 X5R; Part GRM155R60J224KE01D
C809, C810: 2.2uF/16V; 0805; Rating 16V/10%; Rating2 X7R; Part GRM21BR71C225KA12L
C812, C813: 2.2nF; 0603; Rating 50V/5%; Rating2 X7R; Part GRM188R71H222JA01D
C815: 22uF; 0603; Rating 6.3V/20%; Rating2 X5R; Part GRM188R60J226ME0D
R801: 0R/0603; 0603; Rating 1% / Thick Film; Part RC0603FR-070RL
R802, R803: 499R; 0603; Rating 1% / Thick Film; Part RC0603FR-07499RL
TP801, TP802, TP803, TP804: TP; TP_10; Rating NoMask; Part TestPoint
U803: PCM5121; TSSOP-28_4.4x9.7mm_Pitch0.65mm; Rating 106dB DAC BurrBrown; Rating2 HW VOLUME; Part PCM5121PWR

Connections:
+3V3_SNVS: C805.2, C811.2, C814.1, C815.1, U803.1 (CPVDD), U803.8 (AVDD), U803.18 (MODE2), U803.28 (DVDD); also elsewhere on the board
GND: R801.1; also elsewhere on the board
GNDA: C805.1, C808.1, C809.1, C811.1, C812.1, C813.1, C814.2, C815.2, R801.2, U803.3 (CPGND), U803.9 (AGND), U803.10 (VCOM), U803.16 (ADR2), U803.17 (MODE1), U803.24 (ADR1), U803.27 (DGND); also elsewhere on the board
I2C4_SCL: U803.12 (SCL); also elsewhere on the board
I2C4_SDA: U803.11 (SDA); also elsewhere on the board
L_PHONE: C812.2, R802.1; also elsewhere on the board
MUTE_PCM: U803.25 (XSMT); also elsewhere on the board
unnamed: C808.2, U803.26 (LDOO)
unnamed: C809.2, U803.5 (VNEG)
unnamed: C810.1, U803.2 (CAPP)
unnamed: C810.2, U803.4 (CAPM)
unnamed: R802.2, U803.6 (OUTL)
unnamed: R803.2, U803.7 (OUTR)
R_PHONE: C813.2, R803.1; also elsewhere on the board
SAI2_MCLK: TP804.1, U803.20 (SCK); also elsewhere on the board
SAI2_TX_BCK: TP803.1, U803.21 (BCK); also elsewhere on the board
SAI2_TX_DATA: TP802.1, U803.22 (DIN); also elsewhere on the board
SAI2_TX_LRCK: TP801.1, U803.23 (LRCK); also elsewhere on the board

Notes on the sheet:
MODE1 = Low, MODE2 = High: I2C mode
Split ground plane
ADDR 0x4D
PCM5122 + PCM5142 FOOTPRINT COMPATIBLE

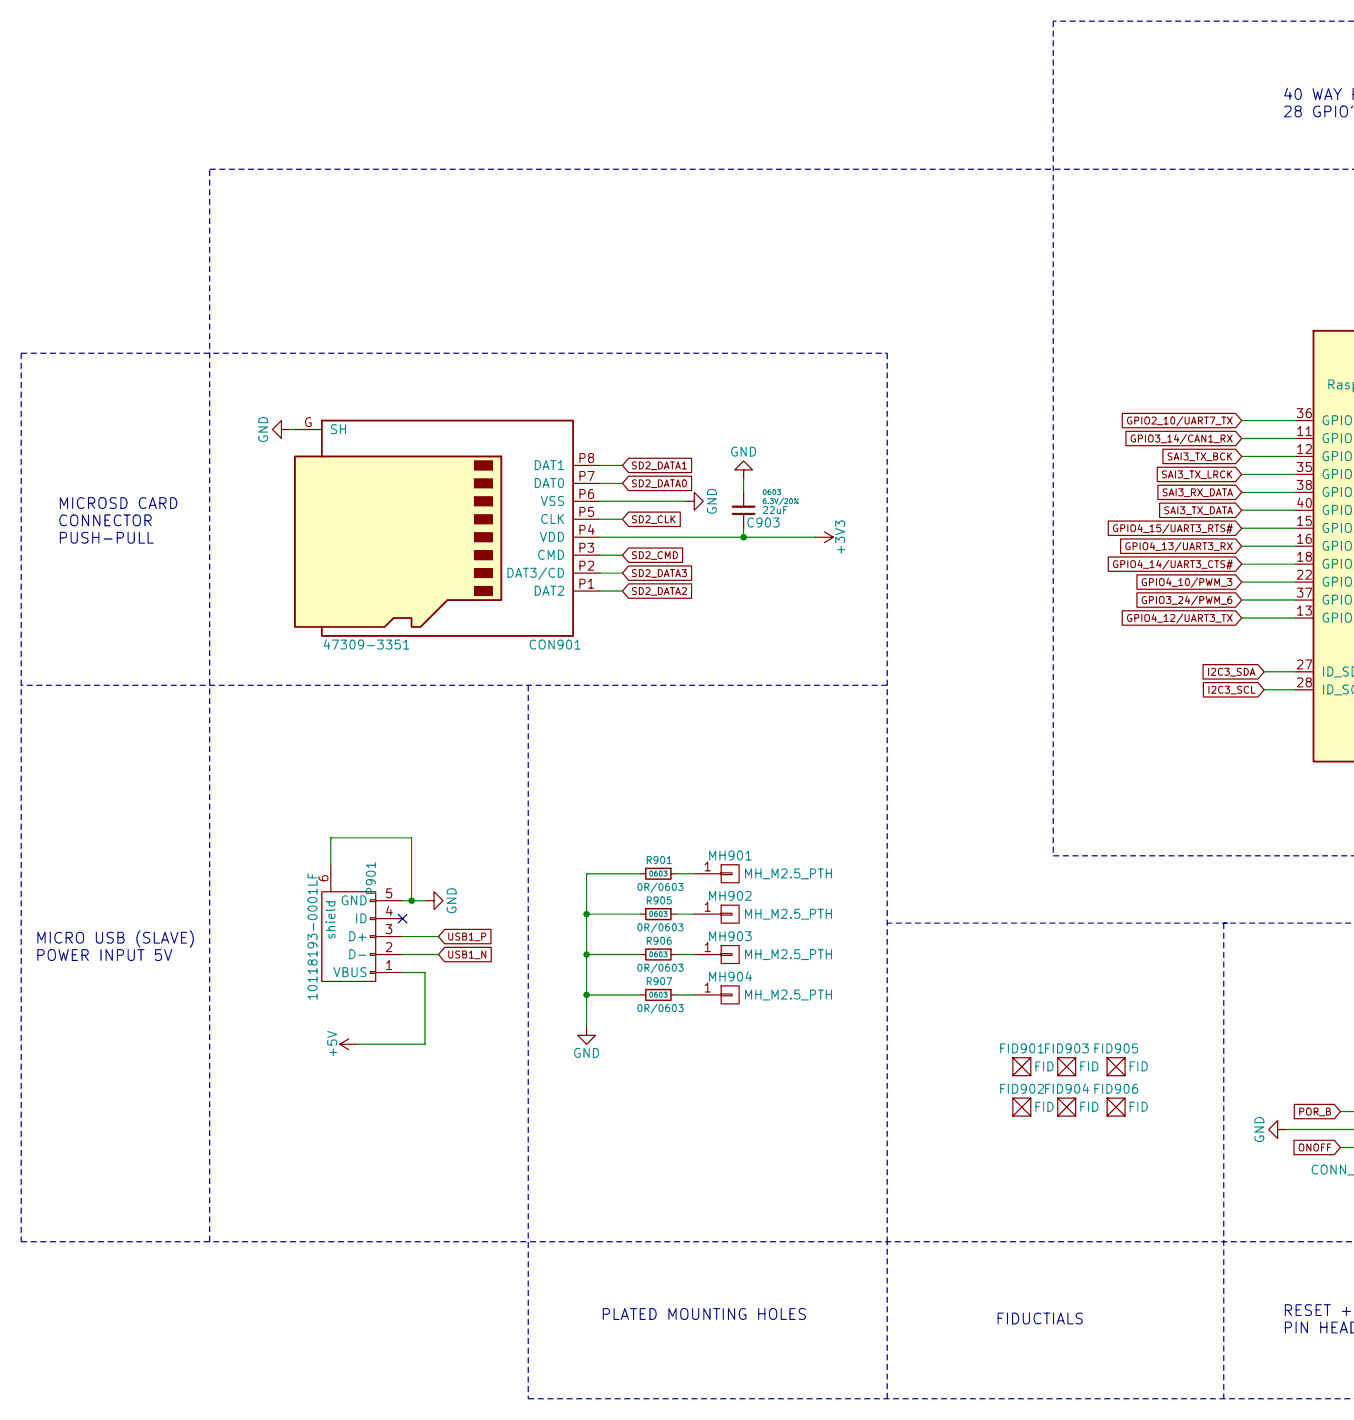
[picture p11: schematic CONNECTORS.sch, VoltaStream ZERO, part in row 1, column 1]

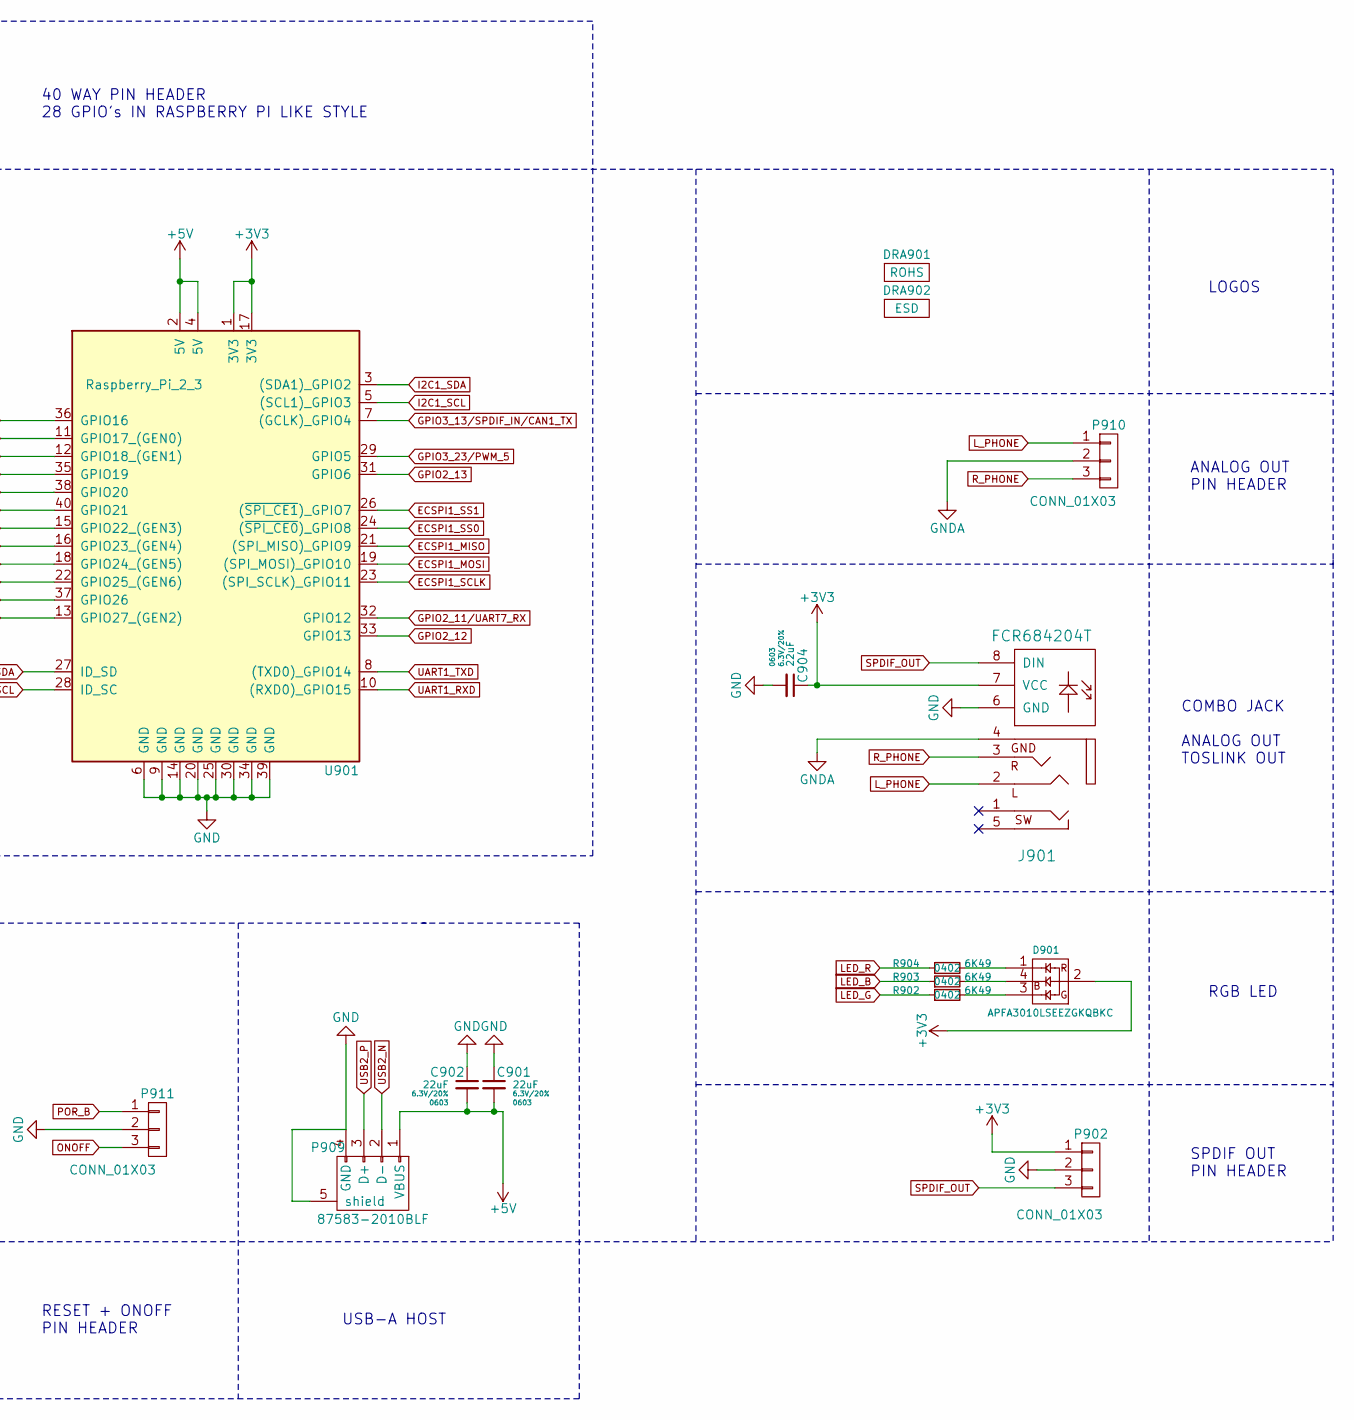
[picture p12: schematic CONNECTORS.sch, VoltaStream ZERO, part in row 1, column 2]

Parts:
C901, C902, C903, C904: 22uF; 0603; Rating 6.3V/20%; Rating2 X5R; Part GRM188R60J226ME0D
CON901: 47309-3351; Rating MicroSD connector; Rating2 Push-Pull SHORT 2MM; Part 47309-3351
D901: APFA3010LSEEZGKQBKC; Rating RGB 90 DEG; Rating2 2mA; Part APFA3010LSEEZGKQ
DRA901: ROHS; Logo_silk_ROHS_5x2.8mm
DRA902: ESD; ESD-Logo_6.6x6mm_SilkScreen
FID901, FID902, FID903, FID904, FID905, FID906: FID; Fiducial_1mm; Rating NoMask; Part Fiductial
J901: FCR684204T; Rating 3.5mm HP + TOSLINK; Part FCR684204T
MH901, MH902, MH903, MH904: MH_M2.5_PTH; MountingHole_2.7mm_M2.5_Pad_Via; Rating Mounting Hole M2.5 VIA; Rating2 PTH
P901: 10118193-0001LF; Rating microUSB OTG; Part 10118193-0001LF
P902, P910, P911: CONN_01X03; Pin_Header_Straight_1x03
P909: 87583-2010BLF; Rating USB-A SINGLE SMD; Part 87583-2010BLF
R901, R905, R906, R907: 0R/0603; 0603; Rating 1% / Thick Film; Part RC0603FR-070RL
R902, R903, R904: 6K49; 0402; Rating 1% / Thick Film; Part RC0402FR-076K49L
U901: Raspberry_Pi_2_3; Pin_Header_Straight_2x20

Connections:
+3V3: C903.1, C904.1, CON901.P4 (VDD), D901.2, J901.7 (VCC), P902.1, U901.1 (3V3), U901.17 (3V3); also elsewhere on the board
+5V: C901.2, C902.2, P901.1 (VBUS), P909.1 (VBUS), U901.2 (5V), U901.4 (5V); also elsewhere on the board
ECSPI1_MISO: U901.21 ((SPI_MISO)_GPIO9); also elsewhere on the board
ECSPI1_MOSI: U901.19 ((SPI_MOSI)_GPIO10); also elsewhere on the board
ECSPI1_SCLK: U901.23 ((SPI_SCLK)_GPIO11); also elsewhere on the board
ECSPI1_SS0: U901.24 ((~SPI_CE0~)_GPIO8); also elsewhere on the board
ECSPI1_SS1: U901.26 ((~SPI_CE1~)_GPIO7); also elsewhere on the board
GND: C901.1, C902.1, C903.2, C904.2, CON901.G (SH), CON901.P6 (VSS), J901.6 (GND), P901.5 (GND), P901.6 (shield), P902.2, P909.4 (GND), P909.5 (shield), P911.2, R901.2, R905.2, R906.2, R907.2, U901.6 (GND), U901.9 (GND), U901.14 (GND), U901.20 (GND), U901.25 (GND), U901.30 (GND), U901.34 (GND), U901.39 (GND); also elsewhere on the board
GNDA: J901.4, P910.2; also elsewhere on the board
GPIO2_10/UART7_TX: U901.36 (GPIO16); also elsewhere on the board
GPIO2_11/UART7_RX: U901.32 (GPIO12); also elsewhere on the board
GPIO2_12: U901.33 (GPIO13); also elsewhere on the board
GPIO2_13: U901.31 (GPIO6); also elsewhere on the board
GPIO3_13/SPDIF_IN/CAN1_TX: U901.7 ((GCLK)_GPIO4); also elsewhere on the board
GPIO3_14/CAN1_RX: U901.11 (GPIO17_(GEN0)); also elsewhere on the board
GPIO3_23/PWM_5: U901.29 (GPIO5); also elsewhere on the board
GPIO3_24/PWM_6: U901.37 (GPIO26); also elsewhere on the board
GPIO4_10/PWM_3: U901.22 (GPIO25_(GEN6)); also elsewhere on the board
GPIO4_12/UART3_TX: U901.13 (GPIO27_(GEN2)); also elsewhere on the board
GPIO4_13/UART3_RX: U901.16 (GPIO23_(GEN4)); also elsewhere on the board
GPIO4_14/UART3_CTS#: U901.18 (GPIO24_(GEN5)); also elsewhere on the board
GPIO4_15/UART3_RTS#: U901.15 (GPIO22_(GEN3)); also elsewhere on the board
I2C1_SCL: U901.5 ((SCL1)_GPIO3); also elsewhere on the board
I2C1_SDA: U901.3 ((SDA1)_GPIO2); also elsewhere on the board
I2C3_SCL: U901.28 (ID_SC); also elsewhere on the board
I2C3_SDA: U901.27 (ID_SD); also elsewhere on the board
LED_B: R903.1; also elsewhere on the board
LED_G: R902.1; also elsewhere on the board
LED_R: R904.1; also elsewhere on the board
L_PHONE: J901.2, P910.1; also elsewhere on the board
unnamed: D901.1, R904.2
unnamed: D901.3, R902.2
unnamed: D901.4, R903.2
unnamed: MH901.1, R901.1
unnamed: MH902.1, R905.1
unnamed: MH903.1, R906.1
unnamed: MH904.1, R907.1
ONOFF: P911.3; also elsewhere on the board
POR_B: P911.1; also elsewhere on the board
R_PHONE: J901.3, P910.3; also elsewhere on the board
SAI3_RX_DATA: U901.38 (GPIO20); also elsewhere on the board
SAI3_TX_BCK: U901.12 (GPIO18_(GEN1)); also elsewhere on the board
SAI3_TX_DATA: U901.40 (GPIO21); also elsewhere on the board
SAI3_TX_LRCK: U901.35 (GPIO19); also elsewhere on the board
SD2_CLK: CON901.P5 (CLK); also elsewhere on the board
SD2_CMD: CON901.P3 (CMD); also elsewhere on the board
SD2_DATA0: CON901.P7 (DAT0); also elsewhere on the board
SD2_DATA1: CON901.P8 (DAT1); also elsewhere on the board
SD2_DATA2: CON901.P1 (DAT2); also elsewhere on the board
SD2_DATA3: CON901.P2 (DAT3/CD); also elsewhere on the board
SPDIF_OUT: J901.8 (DIN), P902.3; also elsewhere on the board
UART1_RXD: U901.10 ((RXD0)_GPIO15); also elsewhere on the board
UART1_TXD: U901.8 ((TXD0)_GPIO14); also elsewhere on the board
USB1_N: P901.2 (D-); also elsewhere on the board
USB1_P: P901.3 (D+); also elsewhere on the board
USB2_N: P909.2 (D-); also elsewhere on the board
USB2_P: P909.3 (D+); also elsewhere on the board

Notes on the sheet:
SPDIF OUT PIN HEADER
RGB LED
COMBO JACK ANALOG OUT TOSLINK OUT
ANALOG OUT PIN HEADER
MICROSD CARD CONNECTOR PUSH-PULL
MICRO USB (SLAVE) POWER INPUT 5V
PLATED MOUNTING HOLES
RESET + ONOFF PIN HEADER
USB-A HOST
40 WAY PIN HEADER 28 GPIO's IN RASPBERRY PI LIKE STYLE
LOGOS
FIDUCTIALS


Board: 4 copper layers, 65.0 x 30.0 mm, 128 parts (0 on the bottom side), 143 nets.

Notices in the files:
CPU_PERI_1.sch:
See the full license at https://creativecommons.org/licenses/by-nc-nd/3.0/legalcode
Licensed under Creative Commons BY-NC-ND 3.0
